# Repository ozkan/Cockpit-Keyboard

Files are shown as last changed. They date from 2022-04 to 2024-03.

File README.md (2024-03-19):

# Cockpit Keyboard

A hot swap system column staggered mechanical keyboard, running QMK Firmware on Pro Micro controllers. 

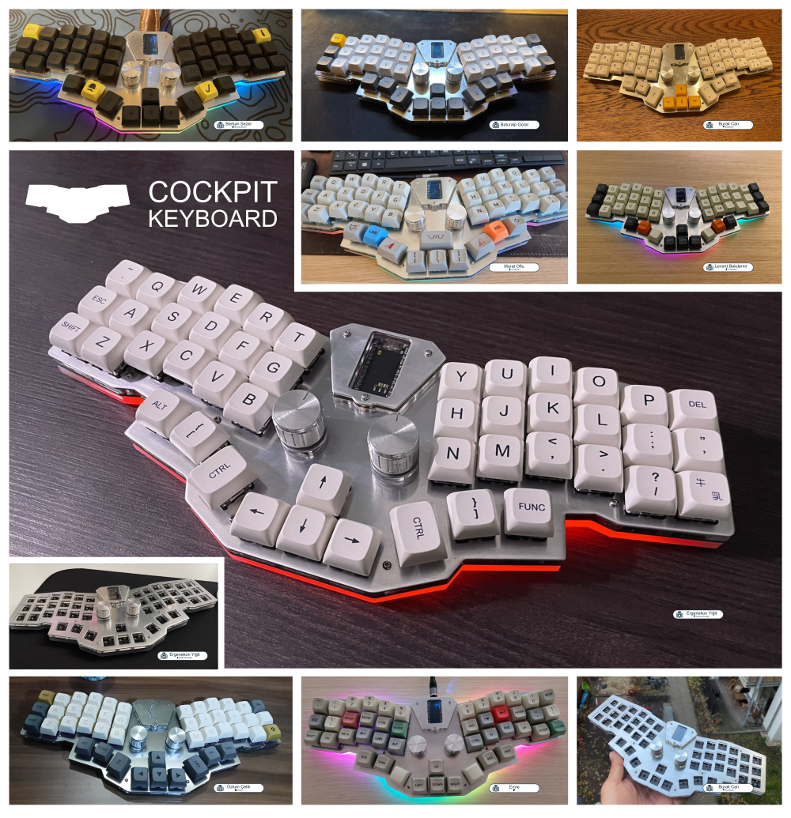
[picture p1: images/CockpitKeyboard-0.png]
Cockpit Keyboard


## Bill of Materials

| Qty  | Descript |
|---|---|
| 1 | PCB board |
| 1 | Arduino Pro Micro |
| 1 | ProMicro socket 24 pin wide or 2.54 mm pitch female header |
| 48 | Diode 1N4148 THT |
| 2 | EC11 Rotary Encoder |
| 2 | Encoder knob |
| 46 | MX Compatible Key Switch (3pin or 5pin) |
| 46 | MX Compatible Keycap (1U) |
| 13 | M2 Spacer 5mm or 6mm (Standoff ) |
| 26 | M2 Screw 5mm |
| 1 | [Top Plate (1.2mm aluminium or acrylic)](acrylic-plate/) |
| 1 | [Upper Middle Plate (4mm acrylic)](acrylic-plate/) |
| 1 | [Lower Middle Plate (3mm acrylic)](acrylic-plate/) |
| 1 | [Bottom Plate (2mm or 3mm acrylic)](acrylic-plate/) |
| 1 | [Pro Micro Cover (2mm or 3mm acrylic)](acrylic-plate/) |
| 1 | 8 channel WS2812 5050 RGB LED |
| 1 | Tact Switch 6X6 4mm |

## Schematic
schematic

## Firmware
Link to qmk-fork: [https://github.com/ozkan/Cockpit-QMK-config](https://github.com/ozkan/Cockpit-QMK-config)    
Link to zmk-fork: [https://github.com/ozkan/Cockpit-ZMK-config](https://github.com/ozkan/Cockpit-ZMK-config)

### Turkey Mechanical Keyboard Community
Telegram: [mechistanbul](https://t.me/mechistanbul) 

## Thanks
Huge shoutout to [Arda Kılıçdağı ](https://github.com/Ardakilic) for tons of advice and help.

<p align="center">

</p> 
<p align="center">
<a href="https://pcbway.com" >PCBWay</a> graciously offered to sponsor the prototype build of this keyboard   <br>
Thanks PCBWay
</p>

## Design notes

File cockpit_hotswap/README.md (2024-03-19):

# Cockpit Keyboard

> [!WARNING]  
> This version (cockpit_hotswap) has not yet been tested. 

### Bill of Materials

| Qty  | Descript |
|---|---|
| 1 | PCB board |
| 1 | Arduino Pro Micro |
| 1 | ProMicro socket 24 pin wide or 2.54 mm pitch female header |
| 46 | Kaihl Hot-swap sockets |
| 48 | 1N4148 SOD123 Diodes |
| 14 | WS2812B RGB LED Chip, 5050 SMD |
| 1 | Tact Switch RS-282G05A3 |
| 1 | 7-Pin On/Off 1P2T SPDT MSK-12C02 SMD Toggle Slide Switch |
| 2 | EC11 Rotary Encoder |
| 2 | Encoder knob |
| 46 | MX Compatible Key Switch (3pin or 5pin) |
| 46 | MX Compatible Keycap (1U) |
| 13 | M2 Spacer 7mm (Standoff) |
| 26 | M2 Screw 5mm |
| 1 | [Top Plate (1.2mm aluminium or acrylic)](acrylic-plate/) |
| 1 | [Upper Middle Plate (4mm acrylic)](acrylic-plate/) |
| 1 | [Lower Middle Plate (3mm acrylic)](acrylic-plate/) |
| 1 | [Bottom Plate (2mm or 3mm acrylic)](acrylic-plate/) |
| 1 | [Pro Micro Cover (2mm or 3mm acrylic)](acrylic-plate/) |

### PCB Renders 

| | |  
|:---:|:---:|
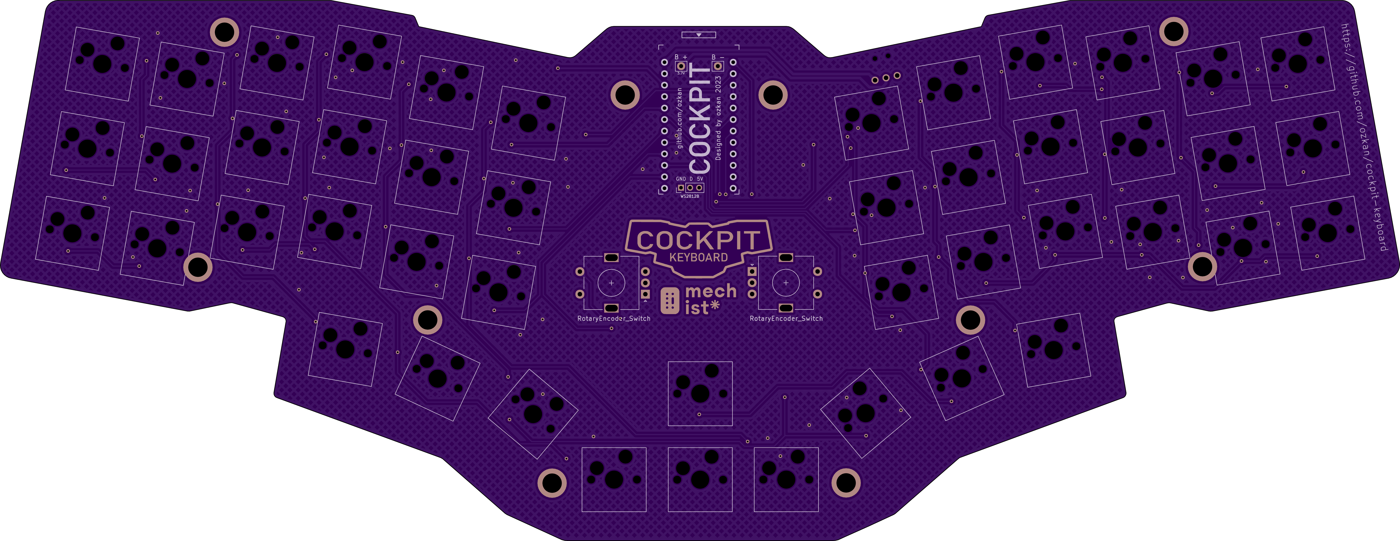
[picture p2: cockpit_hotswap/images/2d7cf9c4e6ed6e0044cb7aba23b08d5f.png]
PCB Top Layer
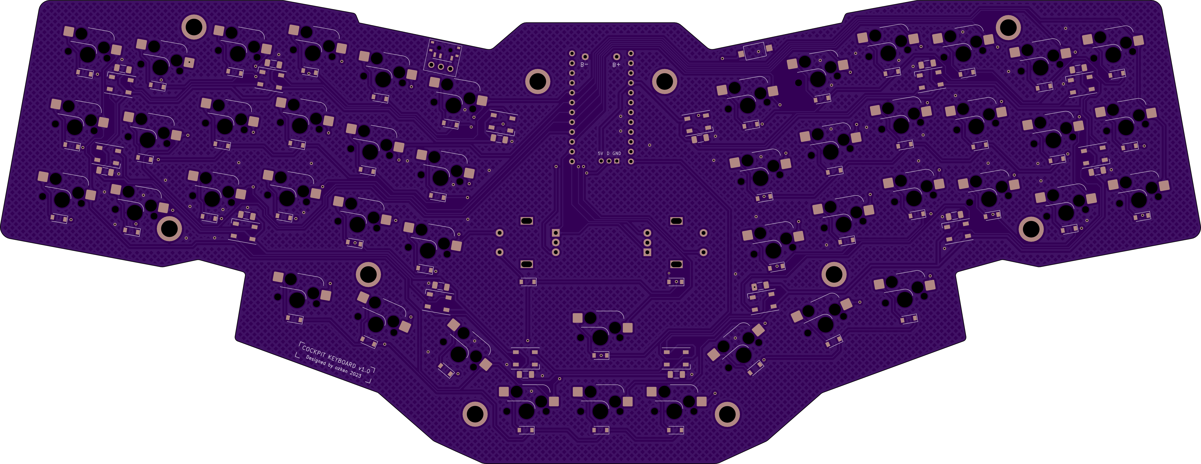
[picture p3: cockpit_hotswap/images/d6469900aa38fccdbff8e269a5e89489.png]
PCB Bottom Layer)
|  | |
|PCB top, full ground plane |PCB bottom, full ground plane|

### Case

| | |  
|:---:|:---:|
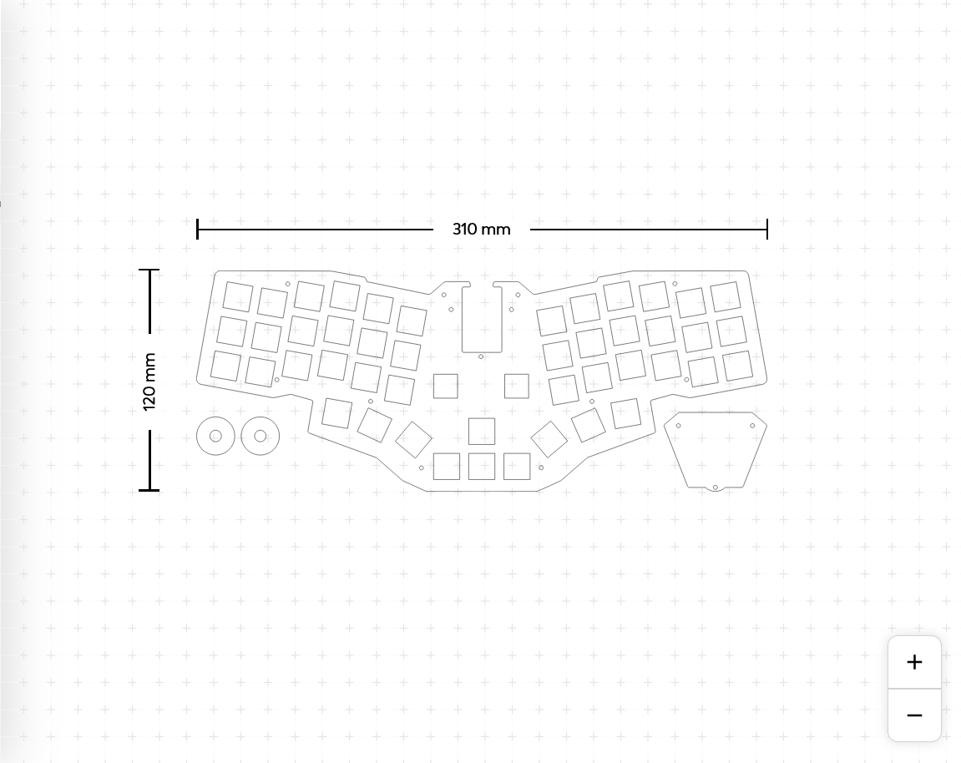
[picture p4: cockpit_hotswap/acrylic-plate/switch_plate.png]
Swtich Plate)
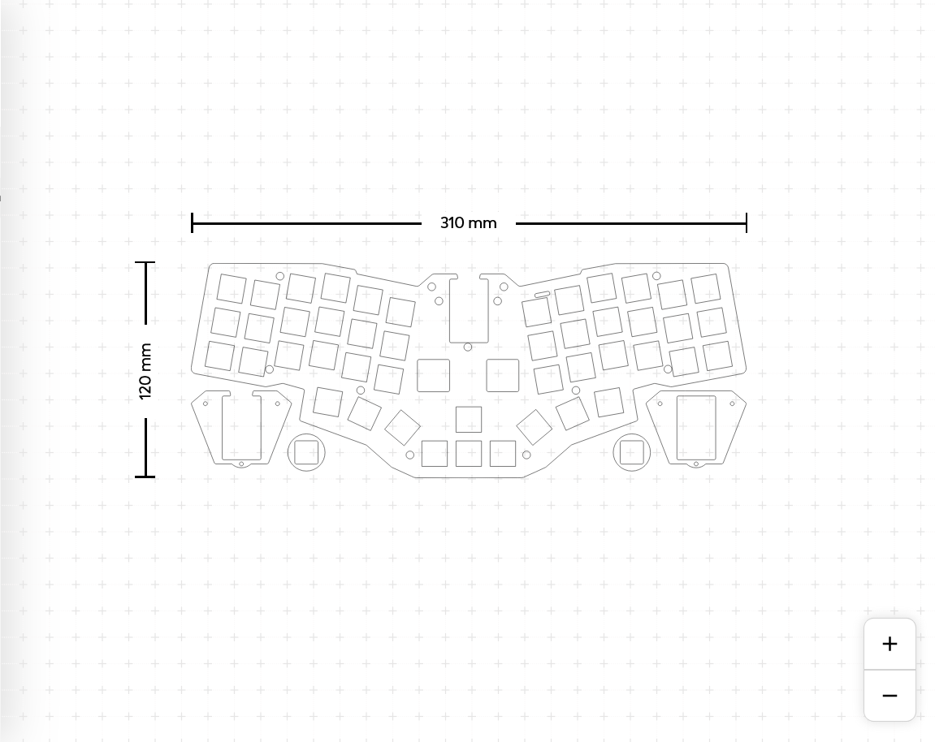
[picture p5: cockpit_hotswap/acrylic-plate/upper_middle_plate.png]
Upper Middle Plate)
|  |  |
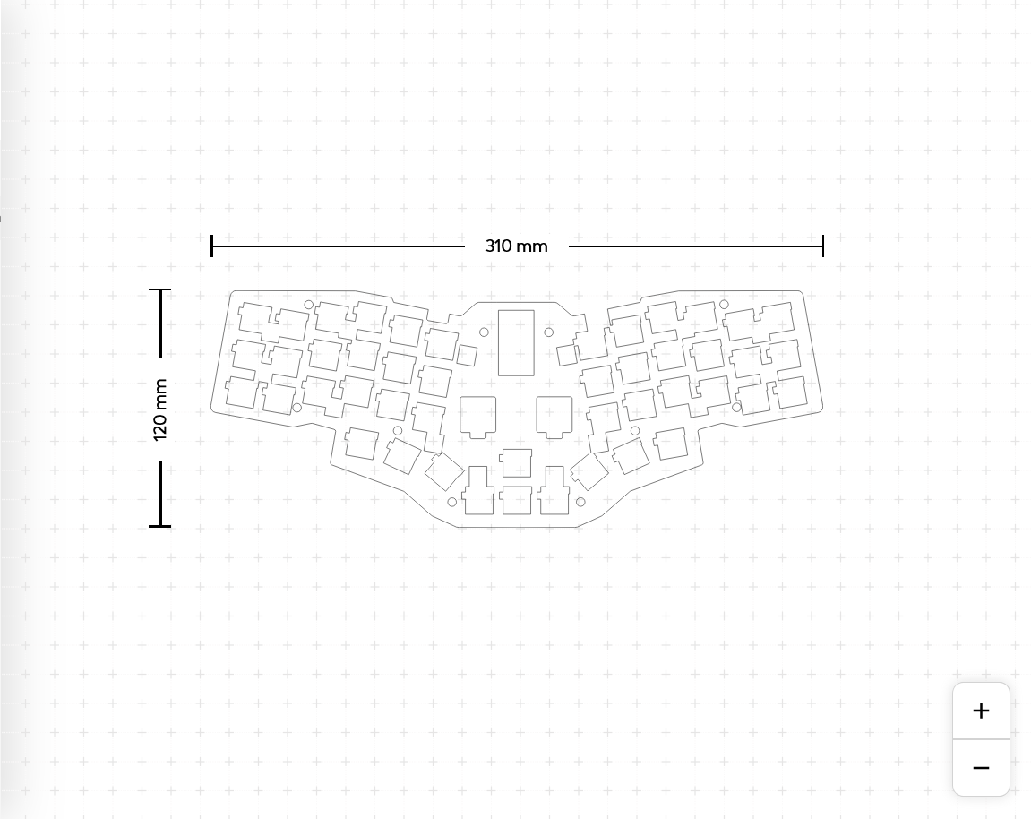
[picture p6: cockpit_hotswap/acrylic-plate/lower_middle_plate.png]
Lower Middle Plate)
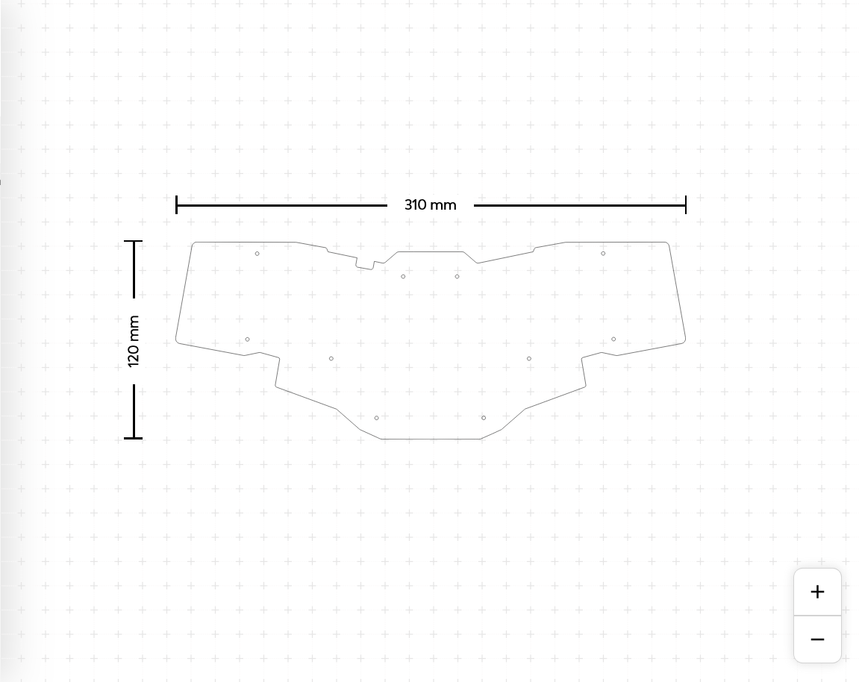
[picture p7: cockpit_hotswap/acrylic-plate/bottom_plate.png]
Bottom Plate)
| | |

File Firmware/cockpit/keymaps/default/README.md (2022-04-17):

### COLEMAK

```
╭──────┬──────┬──────┬──────┬──────┬──────╮                   ╭──────┬──────┬──────┬──────┬──────┬──────╮
│  TAB │  Q   │  W   │  F   │  P   │  G   │                   │  J   │  L   │  U   │  Y   │   ;  │ BSPC │
├──────┼──────┼──────┼──────┼──────┼──────┤                   ├──────┼──────┼──────┼──────┼──────┼──────┤
│ CTRL │  A   │  R   │  S   │NAV T │  D   │                   │  H   │  N   │  E   │  I   │  O   │   "  │
├──────┼──────┼──────┼──────┼──────┼──────┤                   ├──────┼──────┼──────┼──────┼──────┼──────┤
│SFT_CL│ALT Z │CTL X │SFT C │  V   │  B   │                   │  K   │  M   │SFT , │CTL . │ALT / │ ENT  │
╰──────┴──────┴──────┴──────┴──────┴──────┼─────────┬─────────┼──────┴──────┴──────┴──────┴──────┴──────╯
                                          │  MPLY   │  MUTE   │
                    ╭──────┬──────┬───────┼─────────┴─────────┼──────┬──────┬──────╮
                    │  ALT │LOWER │  FNL  │                   │ FNR  │RAISE │  WIN │
                    ╰──────┴──────┴───────┴─────┬──────┬──────┴──────┴──────┴──────╯
                                                │  UP  │
                                         ╭──────┼──────┼──────╮
                                         │ LEFT │ DOWN │ RIGHT│
                                         ╰──────┴──────┴──────╯
```

### LOWER
    
```
╭──────┬──────┬──────┬──────┬──────┬──────╮                   ╭──────┬──────┬──────┬──────┬──────┬──────╮
│ ESC  │      │      │      │      │      │                   │  (   │  )   │  =   │  &   │  |   │ DEL  │
├──────┼──────┼──────┼──────┼──────┼──────┤                   ├──────┼──────┼──────┼──────┼──────┼──────┤
│      │      │      │      │      │      │                   │  {   │  }   │  _   │  $   │  #   │   '  │
├──────┼──────┼──────┼──────┼──────┼──────┤                   ├──────┼──────┼──────┼──────┼──────┼──────┤
│      │      │      │      │      │      │                   │  [   │  ]   │  <   │  >   │  \   │ ENT  │
╰──────┴──────┴──────┴──────┴──────┴──────┼─────────┬─────────┼──────┴──────┴──────┴──────┴──────┴──────╯
                                          │  MPLY   │  MUTE   │
                    ╭──────┬──────┬───────┼─────────┴─────────┼──────┬──────┬──────╮
                    │  ALT │LOWER │  FNL  │                   │ FNR  │RAISE │  WIN │
                    ╰──────┴──────┴───────┴─────┬──────┬──────┴──────┴──────┴──────╯
                                                │  UP  │
                                         ╭──────┼──────┼──────╮
                                         │ LEFT │ DOWN │ RIGHT│
                                         ╰──────┴──────┴──────╯
```

### RAISE

```
╭──────┬──────┬──────┬──────┬──────┬──────╮                   ╭──────┬──────┬──────┬──────┬──────┬──────╮
│ ESC  │  /   │  1   │  2   │  3   │  -   │                   │  F1  │  F2  │  F3  │  F4  │      │      │
├──────┼──────┼──────┼──────┼──────┼──────┤                   ├──────┼──────┼──────┼──────┼──────┼──────┤
│      │  *   │  4   │  5   │  6   │  +   │                   │  F5  │  F6  │  F7  │  F8  │      │      │
├──────┼──────┼──────┼──────┼──────┼──────┤                   ├──────┼──────┼──────┼──────┼──────┼──────┤
│      │  %   │  7   │  8   │  9   │  0   │                   │  F9  │  F10 │ F11  │  F1  │      │      │
╰──────┴──────┴──────┴──────┴──────┴──────┼─────────┬─────────┼──────┴──────┴──────┴──────┴──────┴──────╯
                                          │  MPLY   │  MUTE   │
                    ╭──────┬──────┬───────┼─────────┴─────────┼──────┬──────┬──────╮
                    │  ALT │LOWER │  FNL  │                   │ FNR  │RAISE │  WIN │
                    ╰──────┴──────┴───────┴─────┬──────┬──────┴──────┴──────┴──────╯
                                                │  UP  │
                                         ╭──────┼──────┼──────╮
                                         │ LEFT │ DOWN │ RIGHT│
                                         ╰──────┴──────┴──────╯
```                                        

### FNR

```
╭──────┬──────┬──────┬──────┬──────┬──────╮                   ╭──────┬──────┬──────┬──────┬──────┬──────╮
│ ESC  │      │      │  €   │  £   │  Ğ   │                   │      │      │      │      │      │      │
├──────┼──────┼──────┼──────┼──────┼──────┤                   ├──────┼──────┼──────┼──────┼──────┼──────┤
│      │  !   │  @   │  Ş   │  ₺   │      │                   │      │      │      │      │      │      │
├──────┼──────┼──────┼──────┼──────┼──────┤                   ├──────┼──────┼──────┼──────┼──────┼──────┤
│      │      │      │  Ç   │      │      │                   │      │      │      │      │      │      │
╰──────┴──────┴──────┴──────┴──────┴──────┼─────────┬─────────┼──────┴──────┴──────┴──────┴──────┴──────╯
                                          │  MPLY   │  MUTE   │
                    ╭──────┬──────┬───────┼─────────┴─────────┼──────┬──────┬──────╮
                    │  ALT │LOWER │  FNL  │                   │ FNR  │RAISE │  WIN │
                    ╰──────┴──────┴───────┴─────┬──────┬──────┴──────┴──────┴──────╯
                                                │  UP  │
                                         ╭──────┼──────┼──────╮
                                         │ LEFT │ DOWN │ RIGHT│
                                         ╰──────┴──────┴──────╯
```

### FNL

```
╭──────┬──────┬──────┬──────┬──────┬──────╮                   ╭──────┬──────┬──────┬──────┬──────┬──────╮
│ ESC  │      │      │      │      │      │                   │      │      │  Ü   │      │  :   │ DEL  │
├──────┼──────┼──────┼──────┼──────┼──────┤                   ├──────┼──────┼──────┼──────┼──────┼──────┤
│      │      │      │      │      │      │                   │      │      │  I   │  I   │  Ö   │   '  │
├──────┼──────┼──────┼──────┼──────┼──────┤                   ├──────┼──────┼──────┼──────┼──────┼──────┤
│      │      │      │      │      │      │                   │      │      │  ^   │  ~   │  ?   │ ENT  │
╰──────┴──────┴──────┴──────┴──────┴──────┼─────────┬─────────┼──────┴──────┴──────┴──────┴──────┴──────╯
                                          │  MPLY   │  MUTE   │
                    ╭──────┬──────┬───────┼─────────┴─────────┼──────┬──────┬──────╮
                    │  ALT │LOWER │  FNL  │                   │ FNR  │RAISE │  WIN │
                    ╰──────┴──────┴───────┴─────┬──────┬──────┴──────┴──────┴──────╯
                                                │  UP  │
                                         ╭──────┼──────┼──────╮
                                         │ LEFT │ DOWN │ RIGHT│
                                         ╰──────┴──────┴──────╯                                    
```

### ARROW

```
╭──────┬──────┬──────┬──────┬──────┬──────╮                   ╭──────┬──────┬──────┬──────┬──────┬──────╮
│ ESC  │      │      │      │      │      │                   │C_PREV│ PGUP │  UP  │      │      │      │
├──────┼──────┼──────┼──────┼──────┼──────┤                   ├──────┼──────┼──────┼──────┼──────┼──────┤
│      │      │      │      │NAV T │      │                   │ HOME │ LEFT │ DOWN │ RGHT │ END  │MPLY  │
├──────┼──────┼──────┼──────┼──────┼──────┤                   ├──────┼──────┼──────┼──────┼──────┼──────┤
│      │      │      │      │      │      │                   │C_NEXT│PGDOWN│      │VLDOWN│ VLUP │MUTE  │
╰──────┴──────┴──────┴──────┴──────┴──────┼─────────┬─────────┼──────┴──────┴──────┴──────┴──────┴──────╯
                                          │  MPLY   │  MUTE   │
                    ╭──────┬──────┬───────┼─────────┴─────────┼──────┬──────┬──────╮
                    │  ALT │LOWER │  FNL  │                   │ FNR  │RAISE │  WIN │
                    ╰──────┴──────┴───────┴─────┬──────┬──────┴──────┴──────┴──────╯
                                                │  UP  │
                                         ╭──────┼──────┼──────╮
                                         │ LEFT │ DOWN │ RIGHT│
                                         ╰──────┴──────┴──────╯

``` 
### ADJUST

```
╭──────┬──────┬──────┬──────┬──────┬──────╮                   ╭──────┬──────┬──────┬──────┬──────┬──────╮
│      │      │      │      │      │      │                   │      │      │      │      │ QWERY│COLEMK│
├──────┼──────┼──────┼──────┼──────┼──────┤                   ├──────┼──────┼──────┼──────┼──────┼──────┤
│      │      │      │      │      │      │                   │      │      │      │      │      │      │
├──────┼──────┼──────┼──────┼──────┼──────┤                   ├──────┼──────┼──────┼──────┼──────┼──────┤
│      │      │      │      │      │      │                   │ RESET│      │      │      │      │      │
╰──────┴──────┴──────┴──────┴──────┴──────┼─────────┬─────────┼──────┴──────┴──────┴──────┴──────┴──────╯
                                          │  MPLY   │  MUTE   │
                    ╭──────┬──────┬───────┼─────────┴─────────┼──────┬──────┬──────╮
                    │  ALT │LOWER │  FNL  │                   │ FNR  │RAISE │  WIN │
                    ╰──────┴──────┴───────┴─────┬──────┬──────┴──────┴──────┴──────╯
                                                │  UP  │
                                         ╭──────┼──────┼──────╮
                                         │ LEFT │ DOWN │ RIGHT│
                                         ╰──────┴──────┴──────╯
```

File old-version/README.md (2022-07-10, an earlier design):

# Cockpit Keyboard

A hot swap system for Handwire builds column staggered mechanical keyboard, running QMK Firmware on Pro Micro controllers. 

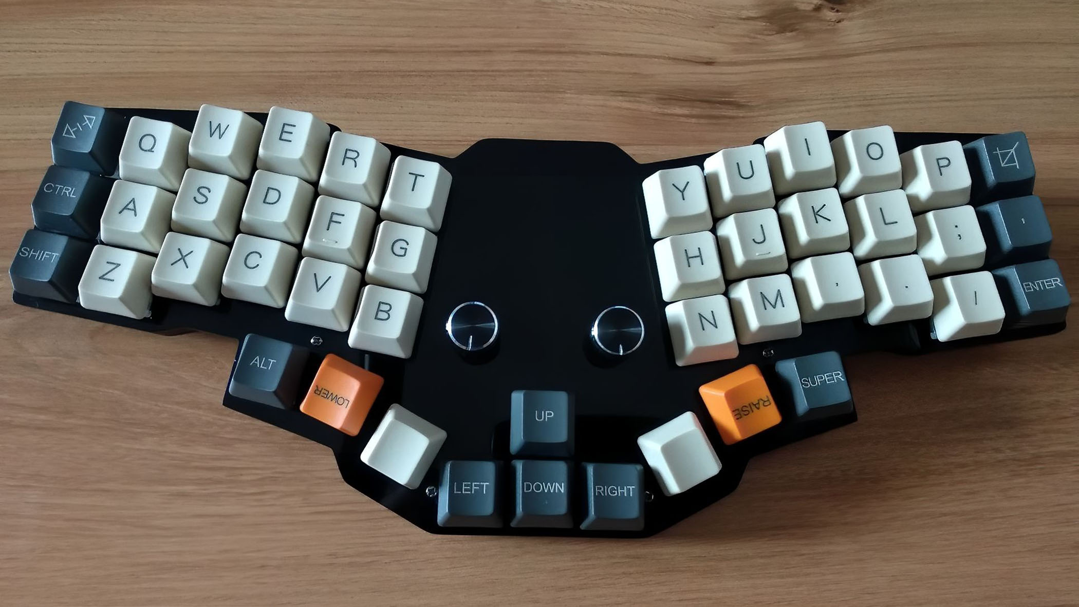
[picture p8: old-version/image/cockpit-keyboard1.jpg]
Cockpit Keyboard
                  
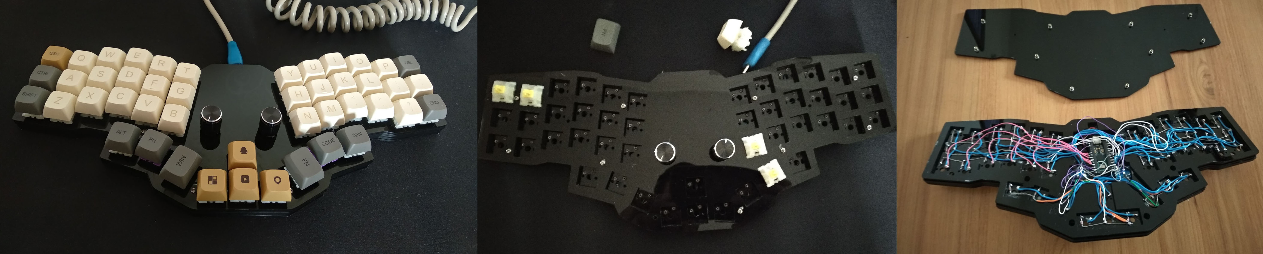
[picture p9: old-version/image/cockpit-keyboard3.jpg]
Cockpit Keyboard
          
## Parts list 

| | Description | Qty  |
| :--- | :----: | ---: |
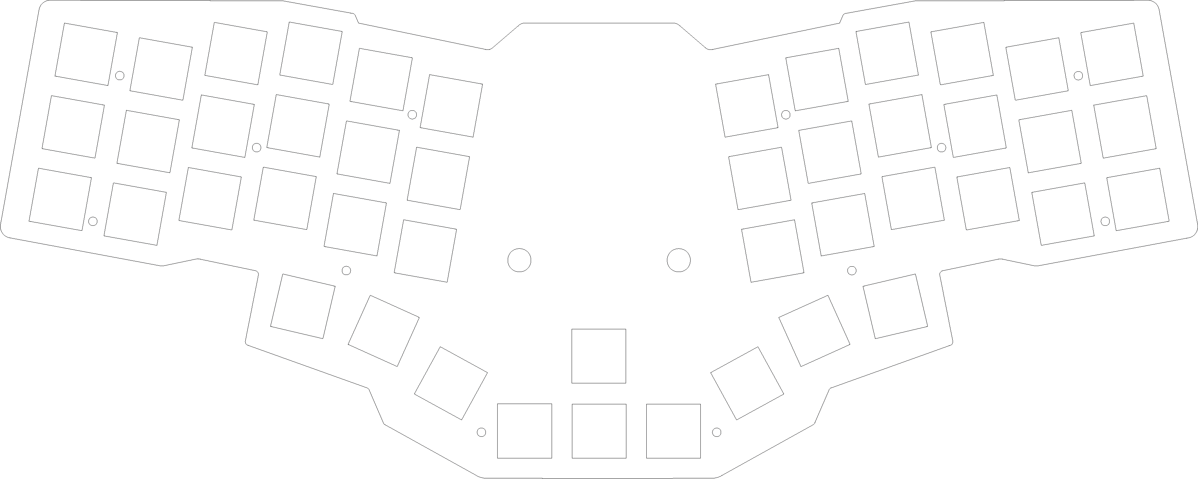
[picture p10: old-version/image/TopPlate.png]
top plate
|  |[Top Plate (1.5mm aluminium or acrylic)](acrylic-plate/top-plate/) | 1 |
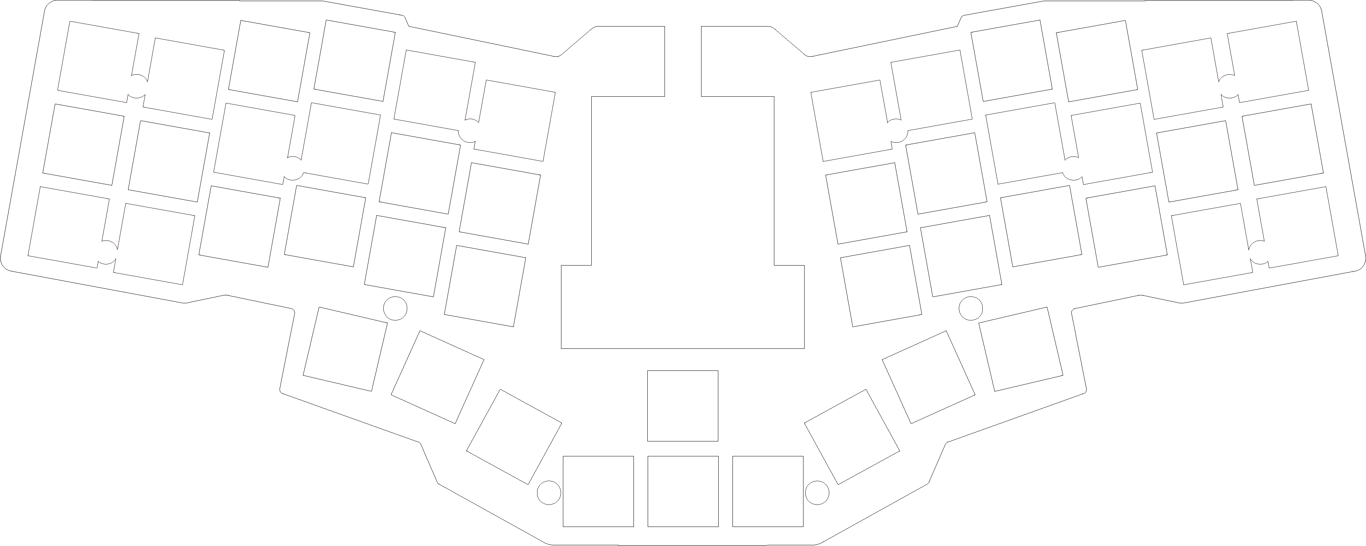
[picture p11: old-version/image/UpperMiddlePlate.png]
upper middle plate
|  |[Upper Middle Plate (3mm acrylic)](acrylic-plate/upper-middle-plate/)| 1 |
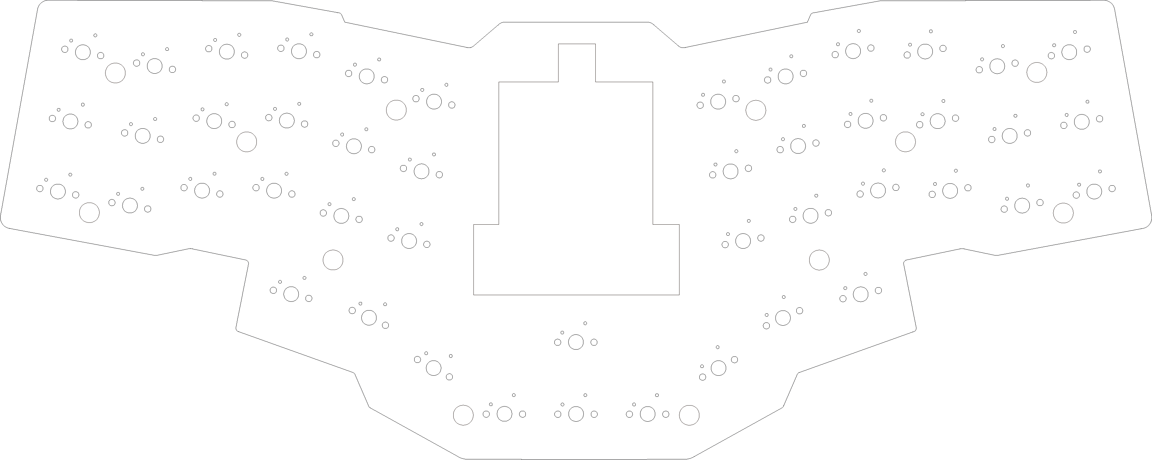
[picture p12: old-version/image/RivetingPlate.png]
riveting plate
|  |[Riveting Plate (2mm acrylic)](acrylic-plate/riveting-plate/) | 1 |
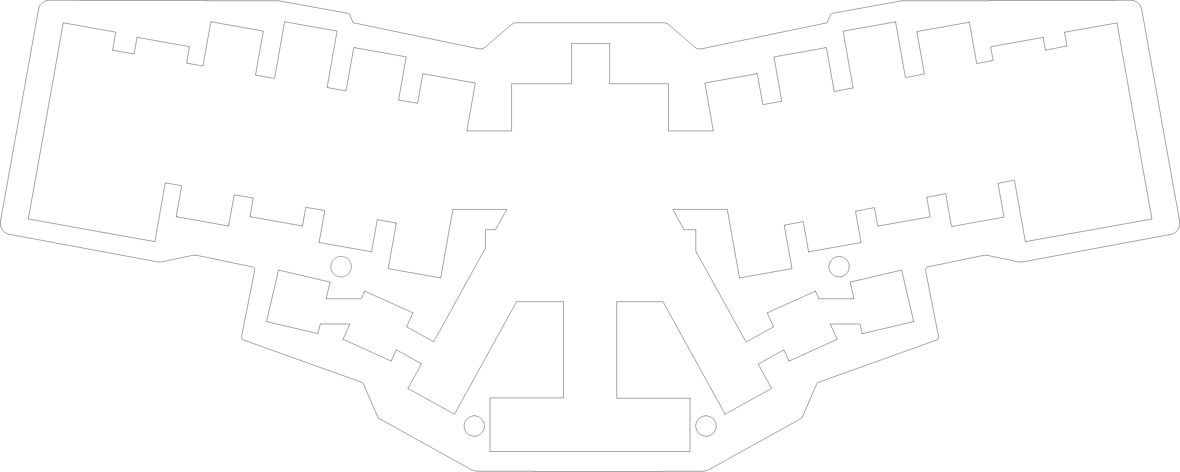
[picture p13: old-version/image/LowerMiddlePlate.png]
lower middle plate
|  |[Lower Middle Plate (3mm acrylic)](acrylic-plate/lower-middle-plate/)| 1 |
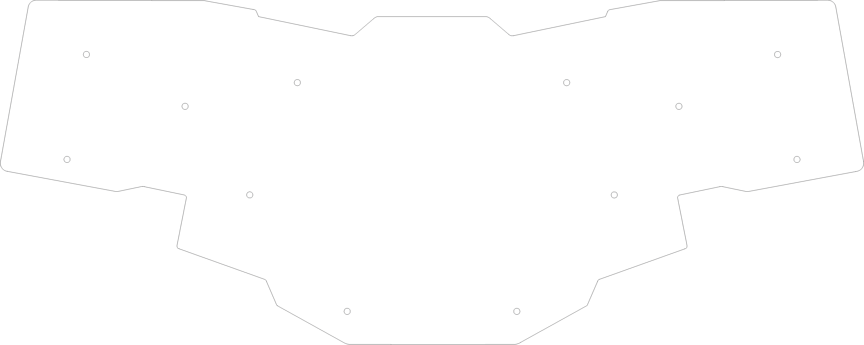
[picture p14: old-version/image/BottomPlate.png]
bottom plate
|  |[Bottom Plate (2mm or 3mm acrylic)](acrylic-plate/bottom-plate/) | 1 |
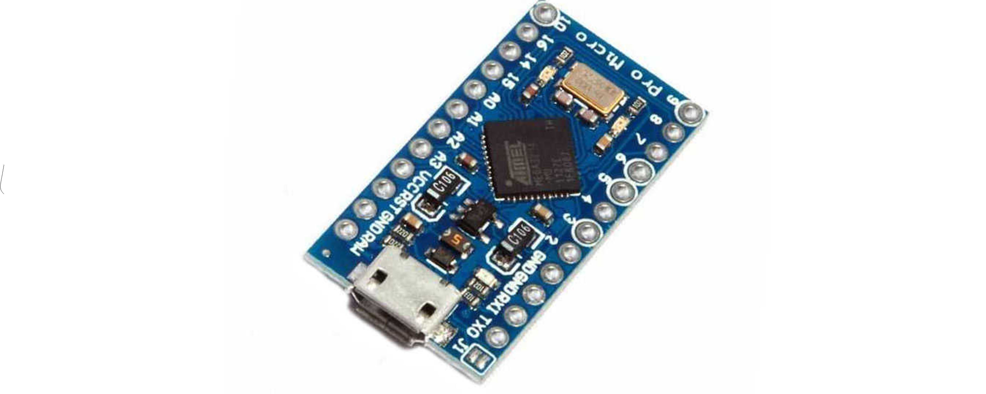
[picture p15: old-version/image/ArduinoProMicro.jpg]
arduino pro micro
|  |Arduino Pro Micro | 1 |
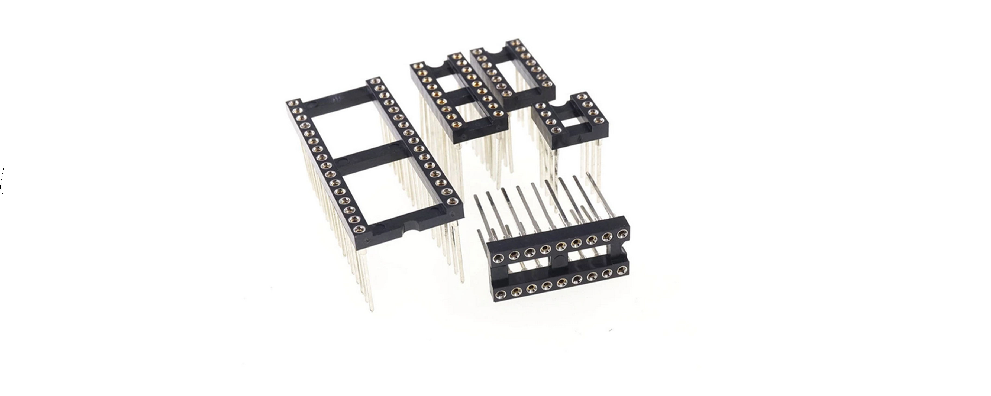
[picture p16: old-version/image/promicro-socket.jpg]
promicro socket
|  |ProMicro Socket 24 Pin Wide (optional) | 1 |
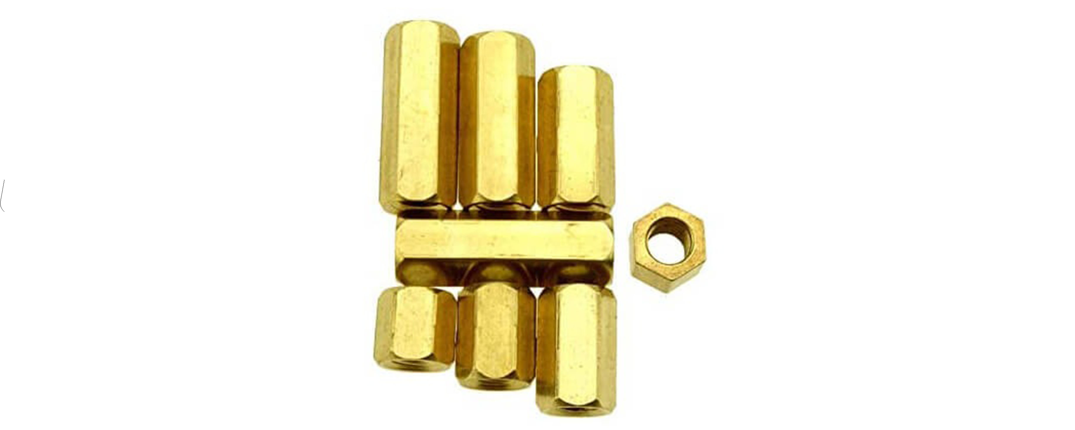
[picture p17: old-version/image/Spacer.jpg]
Spacer
|  |M2 Spacer 5mm or 6mm | 12 |
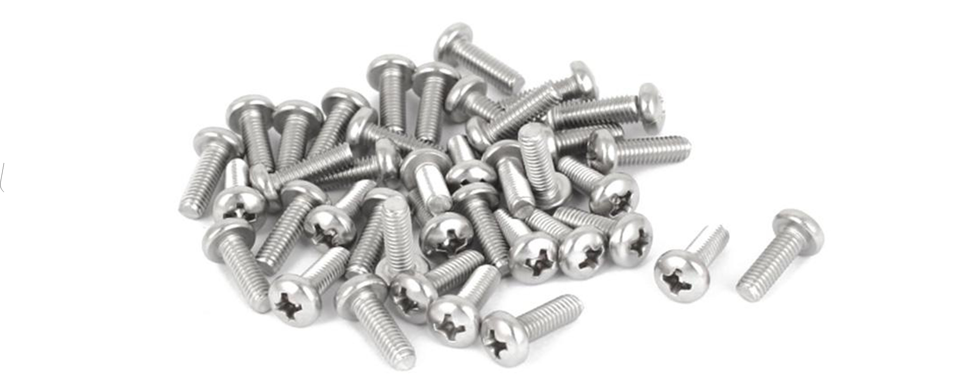
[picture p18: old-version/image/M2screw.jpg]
M2screw
|  |M2 Screw 4mm | 24 |
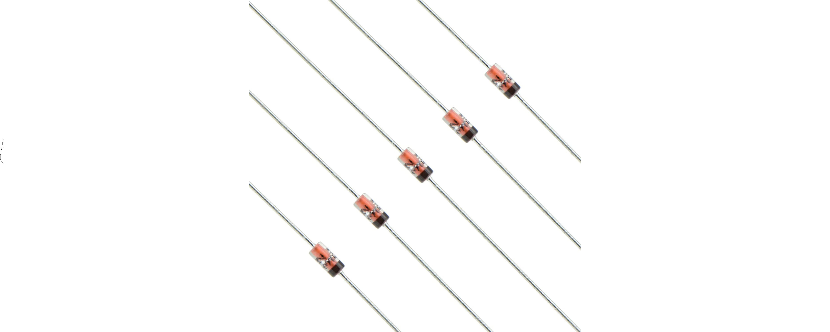
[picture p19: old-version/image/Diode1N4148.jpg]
Diode 1N4148
|  |Diode 1N4148 THT | 48 |
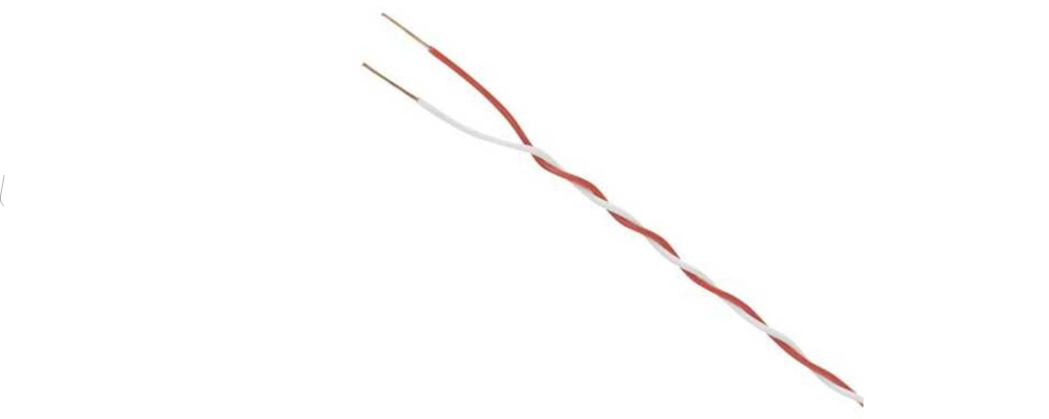
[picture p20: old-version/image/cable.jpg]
cable
|  |Single Core 0.5mm Cable | ~3m  |
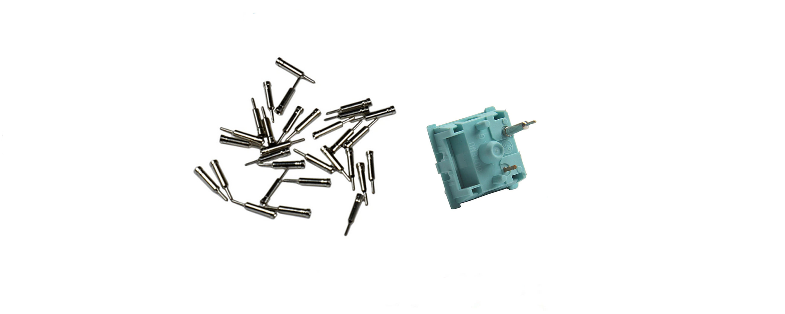
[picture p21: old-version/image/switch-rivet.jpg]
Rivet
|  |Rivet (Hot Swap Sip Socket Similar to Millmax) or 7305-0-15-15-47-27-10-0 Millmax | 92 |
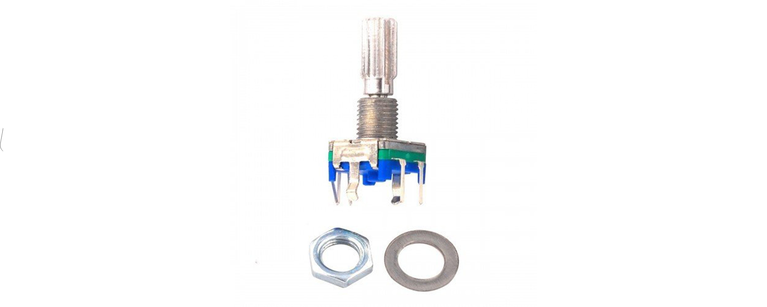
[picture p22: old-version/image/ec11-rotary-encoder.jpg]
Ec11
|  |EC11 Rotary Encoder | 2 |
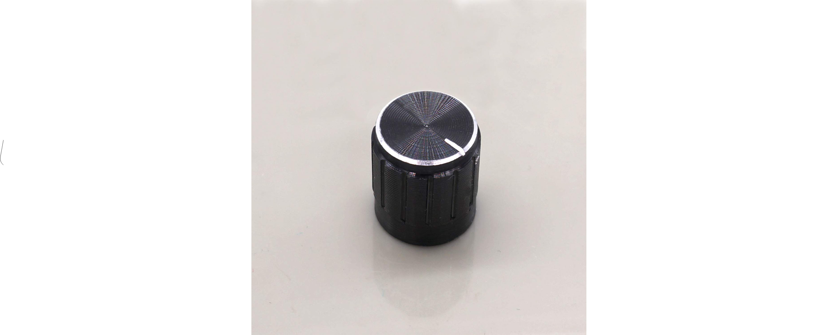
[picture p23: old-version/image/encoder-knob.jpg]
Knob
|  |Knob | 2 |
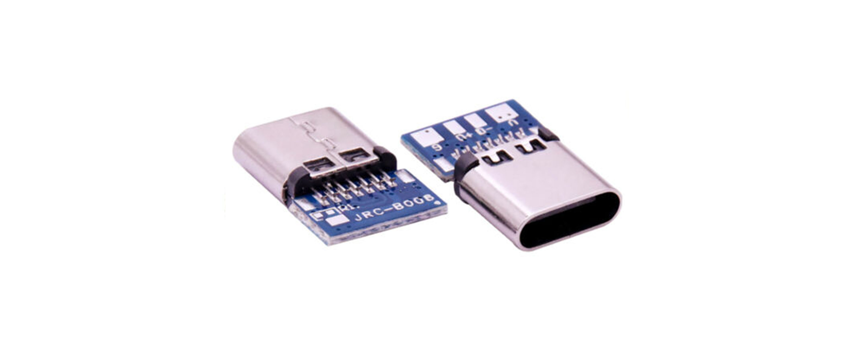
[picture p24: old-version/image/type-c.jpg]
type c
|  |Type C Connector 14 Pin Female | 1 |
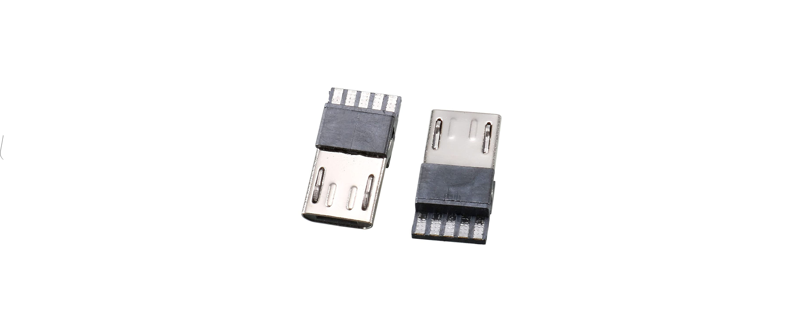
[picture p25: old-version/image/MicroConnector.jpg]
micro connetor
|  |Micro USB Male Type B 5 Terminal Jack Port Solder Connector | 1 |
| switch |MX Compatible Key Switch (3pin or 5pin) | 46 |
| keycaps |MX Compatible Keycap (1U) | 46 |

## Schematic
schematic

## Firmware
[Frimware](Firmware)

### Turkey Mechanical Keyboard Community
[Telegram: mechistanbul](https://t.me/mechistanbul) 

---
Keyboard Maintainer: [ozkan](https://github.com/ozkan)

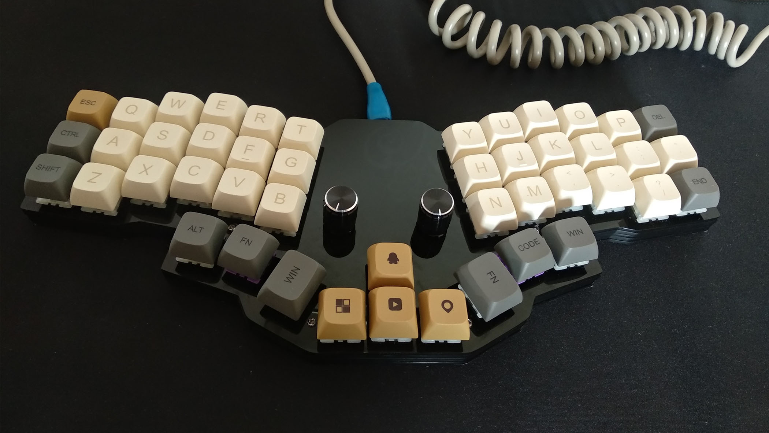
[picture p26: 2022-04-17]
image/cockpit-keyboard2.jpg

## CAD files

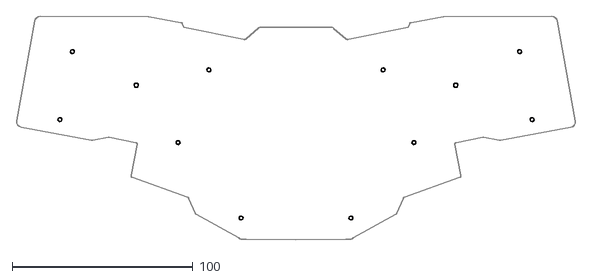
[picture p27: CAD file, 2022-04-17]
acrylic-plate/bottom-plate/BottomPlate.dxf
310.0 x 123.6

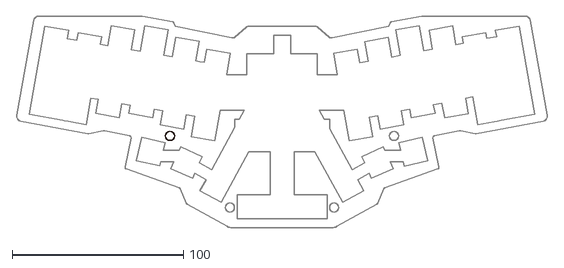
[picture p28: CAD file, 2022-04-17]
acrylic-plate/lower-middle-plate/LowerMiddlePlate.dxf
310.0 x 123.6

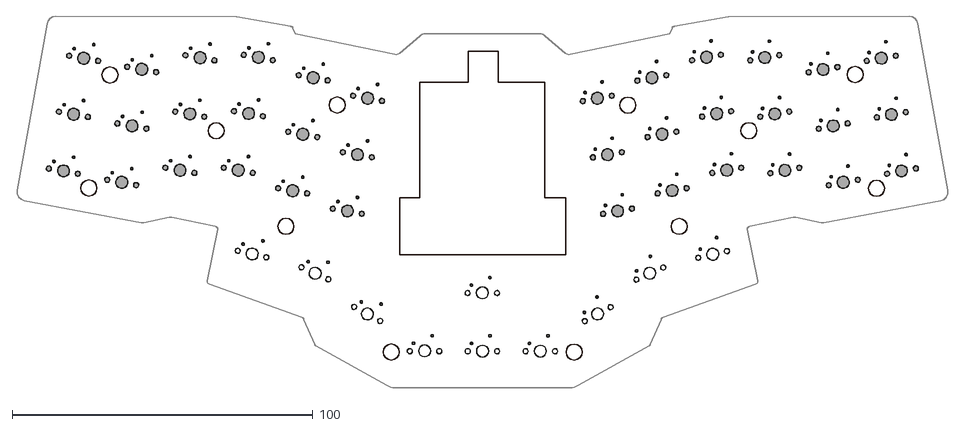
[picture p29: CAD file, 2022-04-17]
acrylic-plate/riveting-plate/RivetingPlate.dxf
310.0 x 123.6

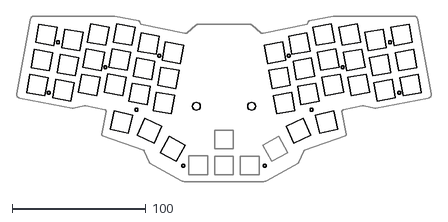
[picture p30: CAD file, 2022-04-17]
acrylic-plate/top-plate/TopPlate.dxf
310.0 x 123.6

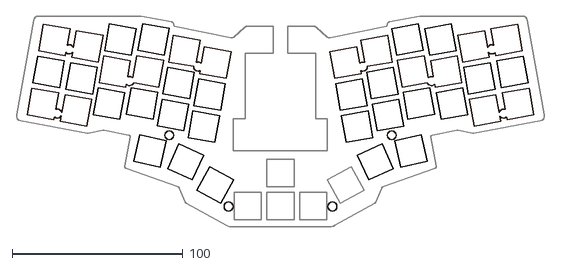
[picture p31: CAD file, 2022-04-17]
acrylic-plate/upper-middle-plate/UpperMiddlePlate.dxf
310.0 x 123.6

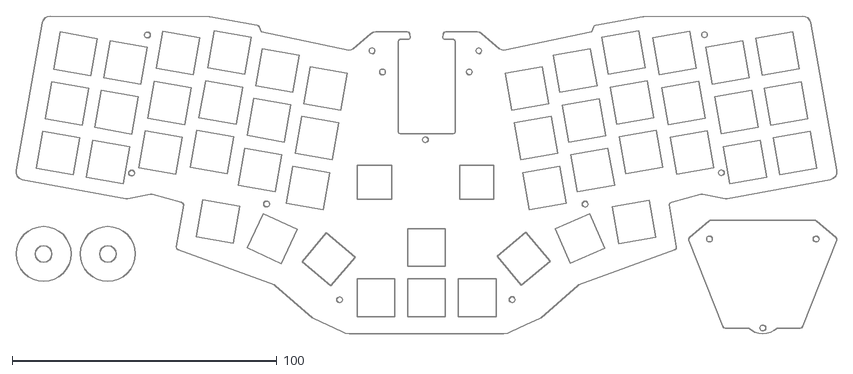
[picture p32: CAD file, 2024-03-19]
cockpit_hotswap/acrylic-plate/switch_plate.dxf
310.0 x 120.0

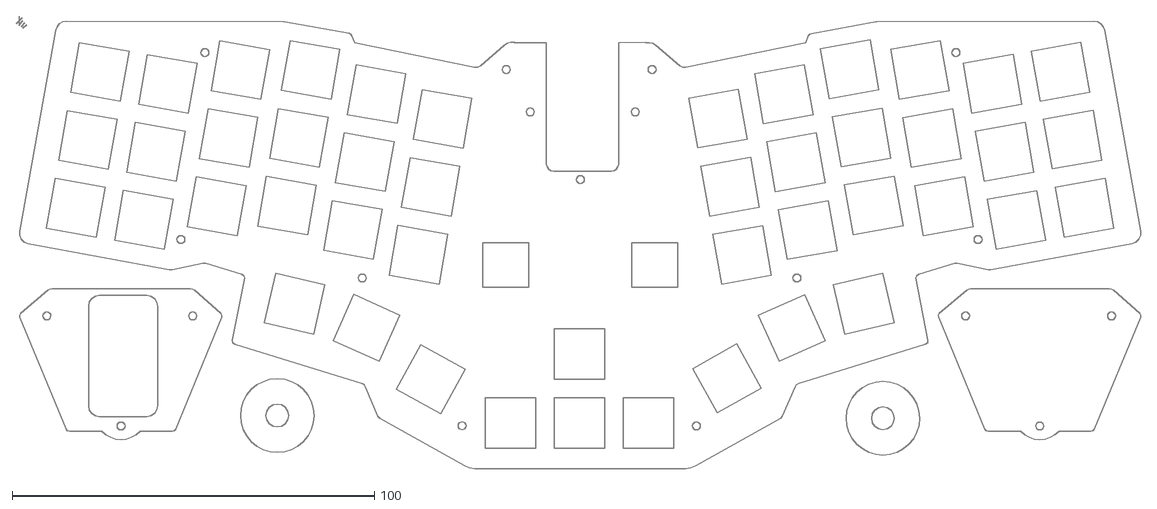
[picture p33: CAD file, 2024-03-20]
cockpit_soldered/acrylic-plate/top.dxf
310.3 x 125.0

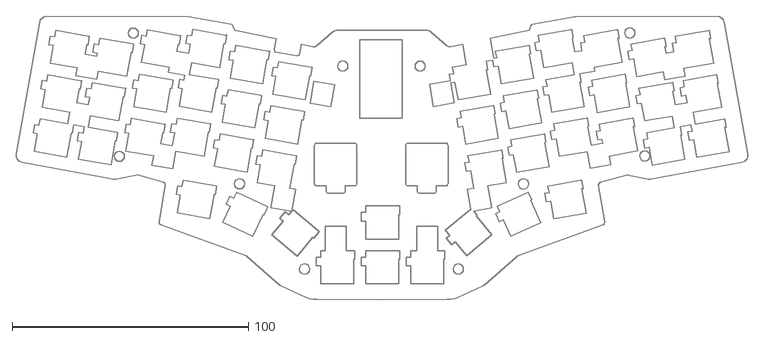
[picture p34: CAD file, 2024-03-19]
cockpit_hotswap/acrylic-plate/lower_middle_plate.dxf
310.0 x 120.0

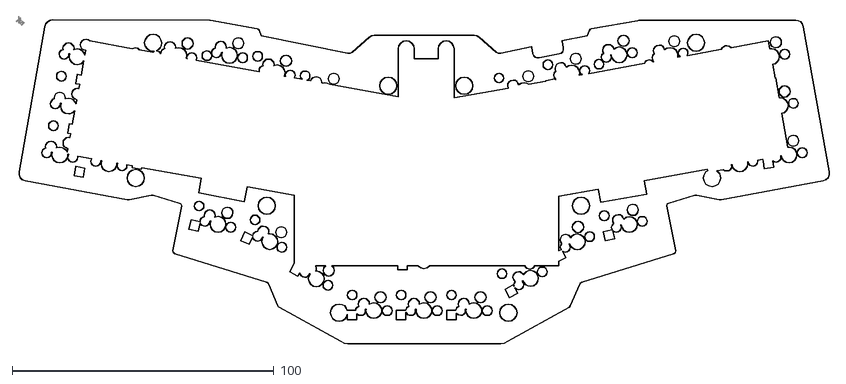
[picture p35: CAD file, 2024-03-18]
cockpit_soldered/acrylic-plate/lower-middle-plate.dxf
310.4 x 125.1

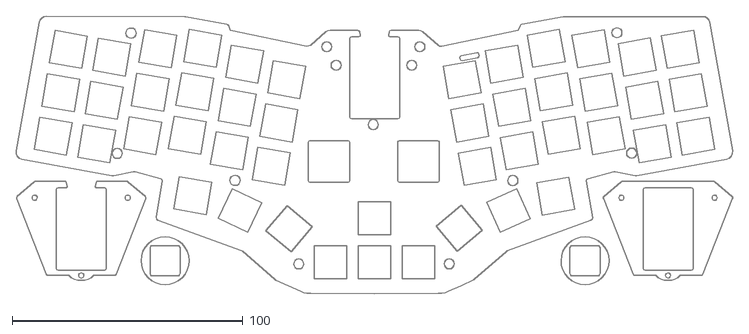
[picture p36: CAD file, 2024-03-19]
cockpit_hotswap/acrylic-plate/upper_middle_plate.dxf
310.1 x 119.9

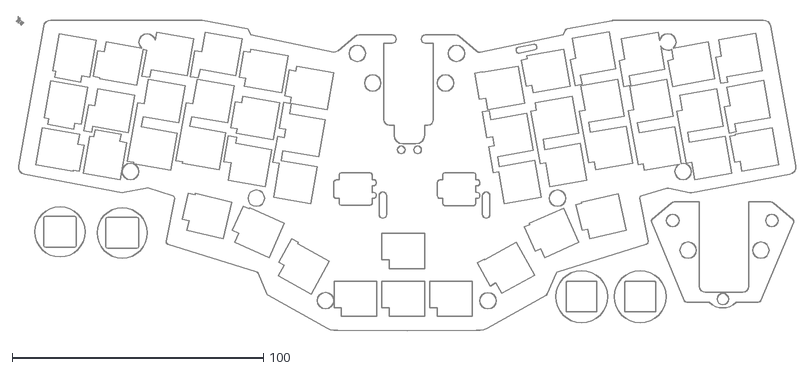
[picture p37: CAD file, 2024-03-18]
cockpit_soldered/acrylic-plate/upper-middle-plate.dxf
310.3 x 125.1

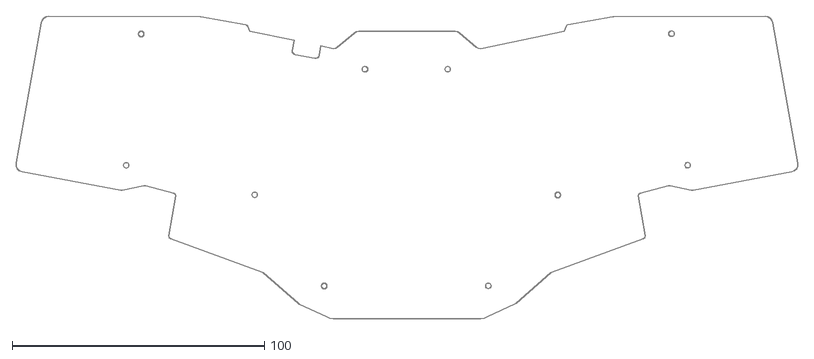
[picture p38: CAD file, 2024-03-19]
cockpit_hotswap/acrylic-plate/bottom_plate.dxf
310.2 x 120.1

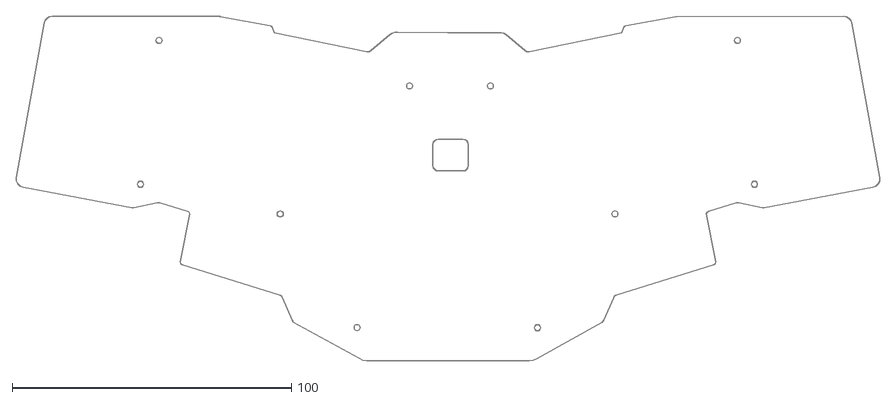
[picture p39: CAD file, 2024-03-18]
cockpit_soldered/acrylic-plate/bottom.dxf
309.4 x 123.6

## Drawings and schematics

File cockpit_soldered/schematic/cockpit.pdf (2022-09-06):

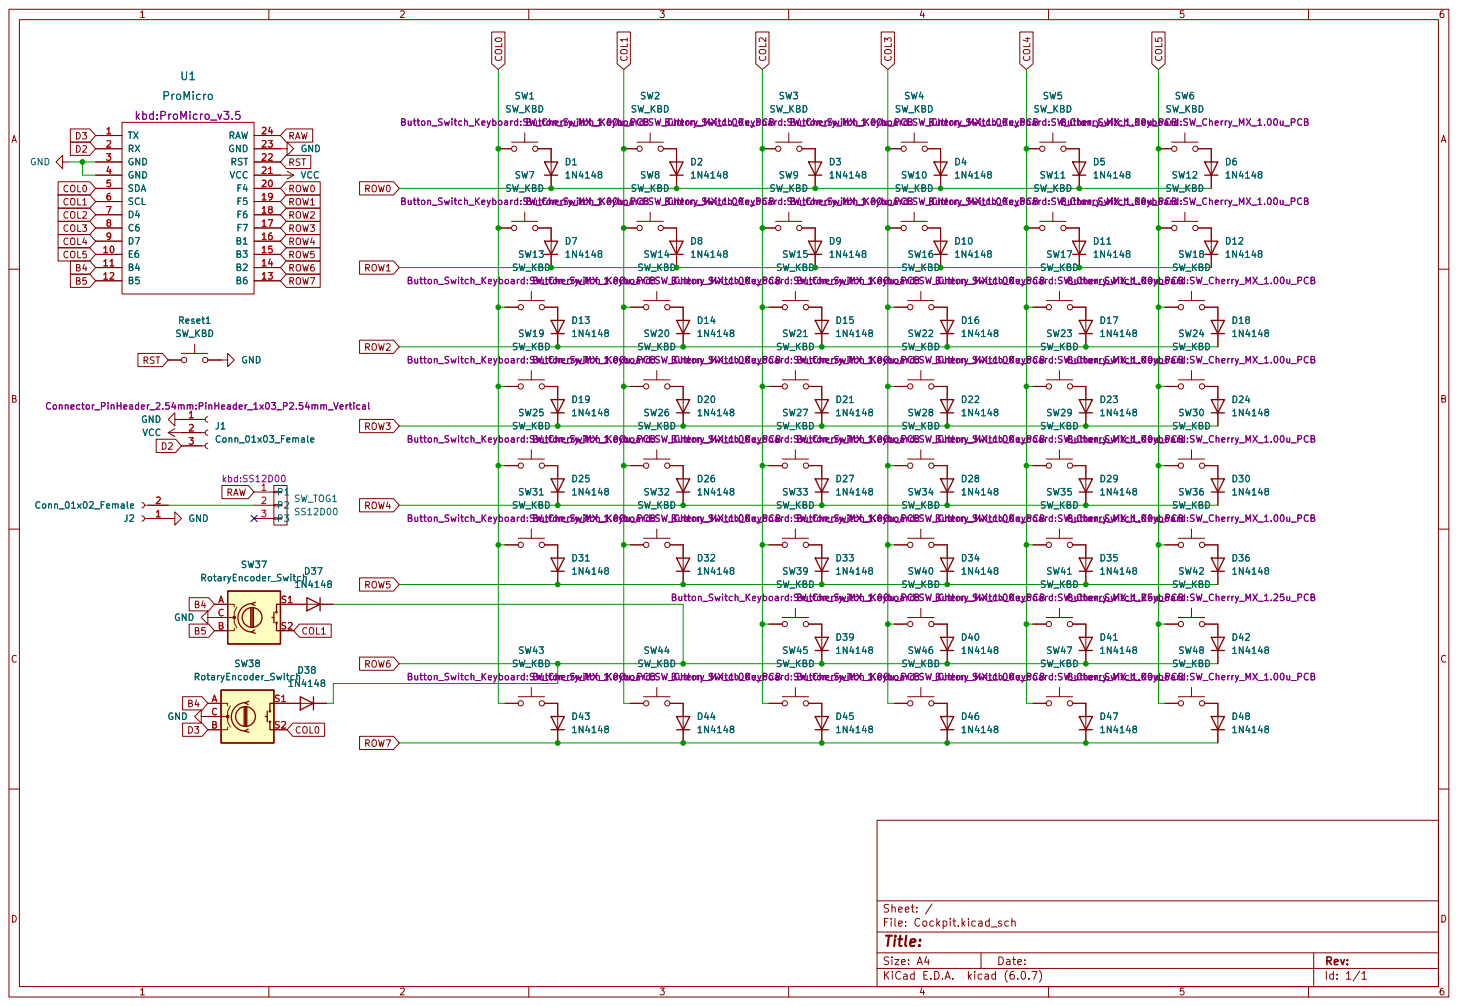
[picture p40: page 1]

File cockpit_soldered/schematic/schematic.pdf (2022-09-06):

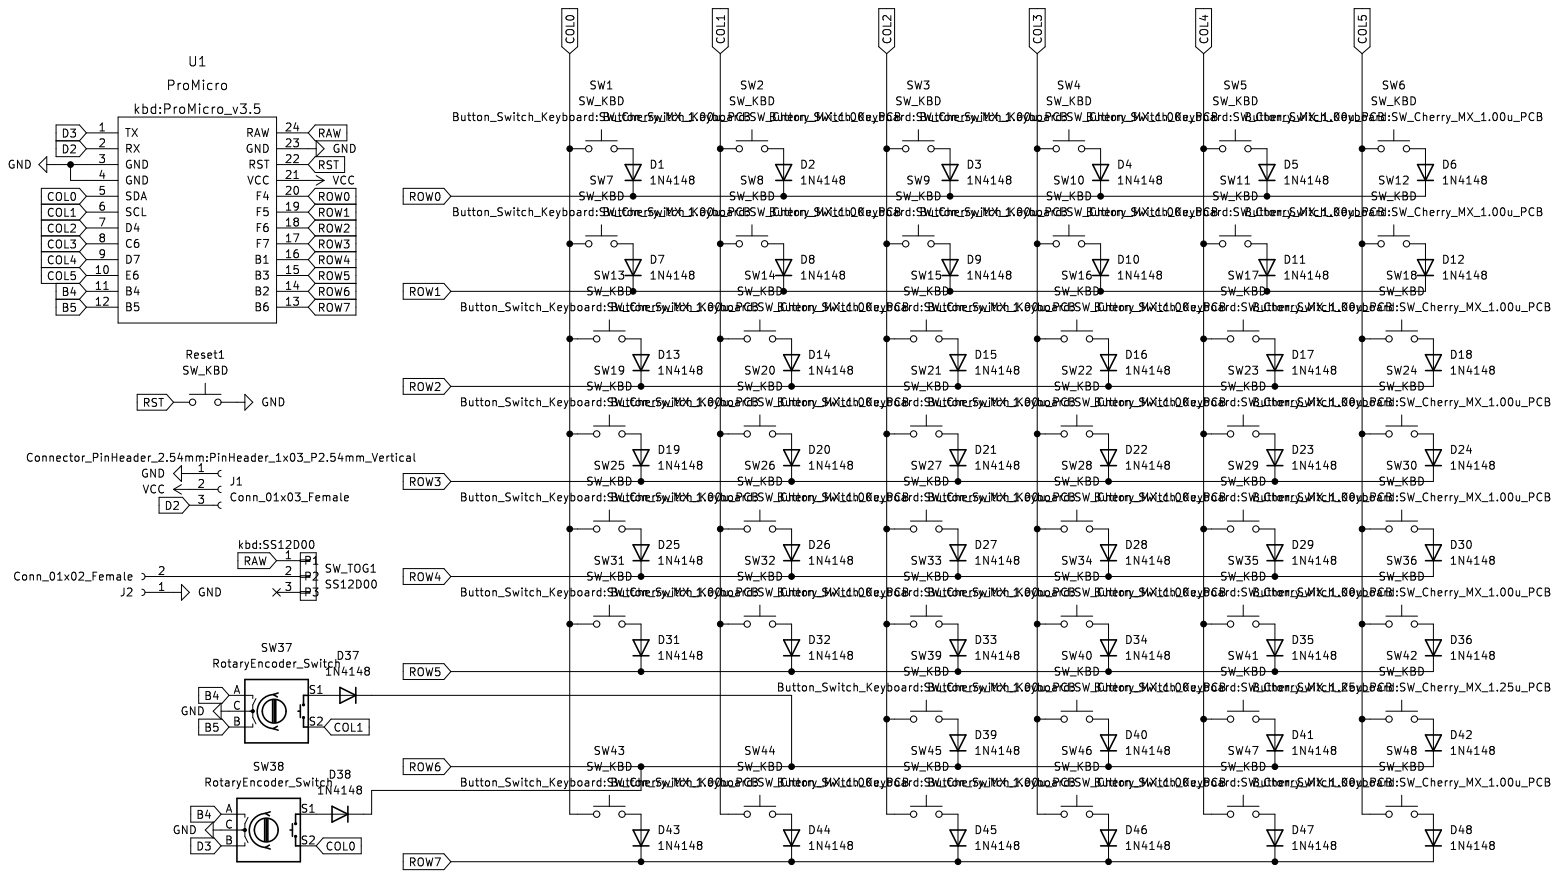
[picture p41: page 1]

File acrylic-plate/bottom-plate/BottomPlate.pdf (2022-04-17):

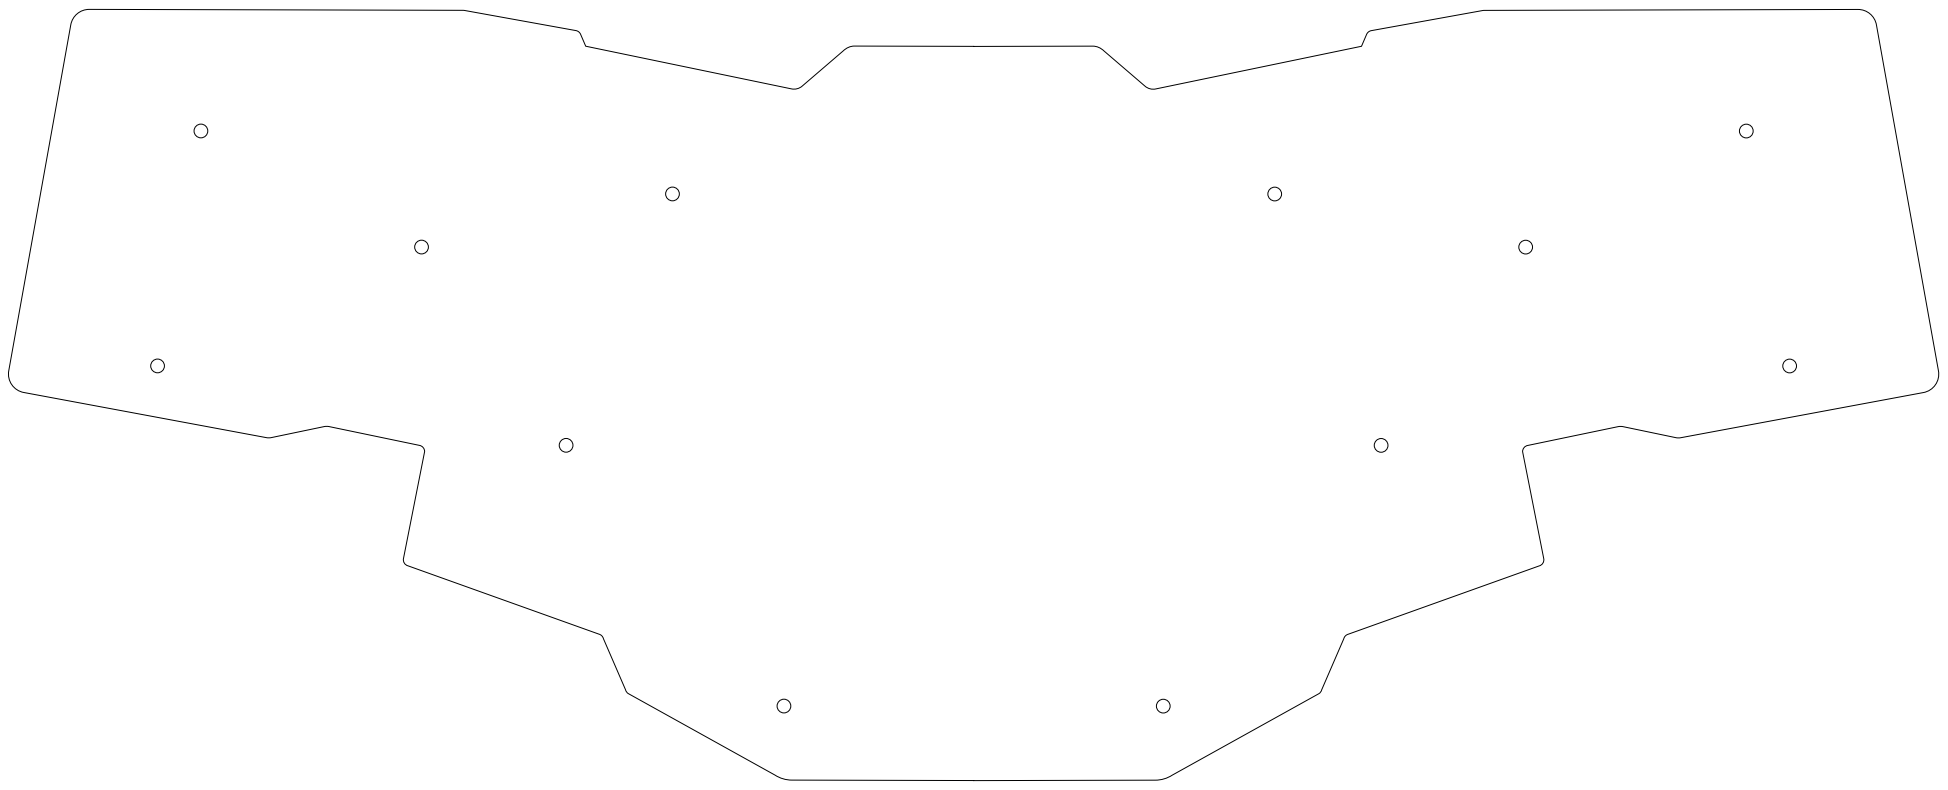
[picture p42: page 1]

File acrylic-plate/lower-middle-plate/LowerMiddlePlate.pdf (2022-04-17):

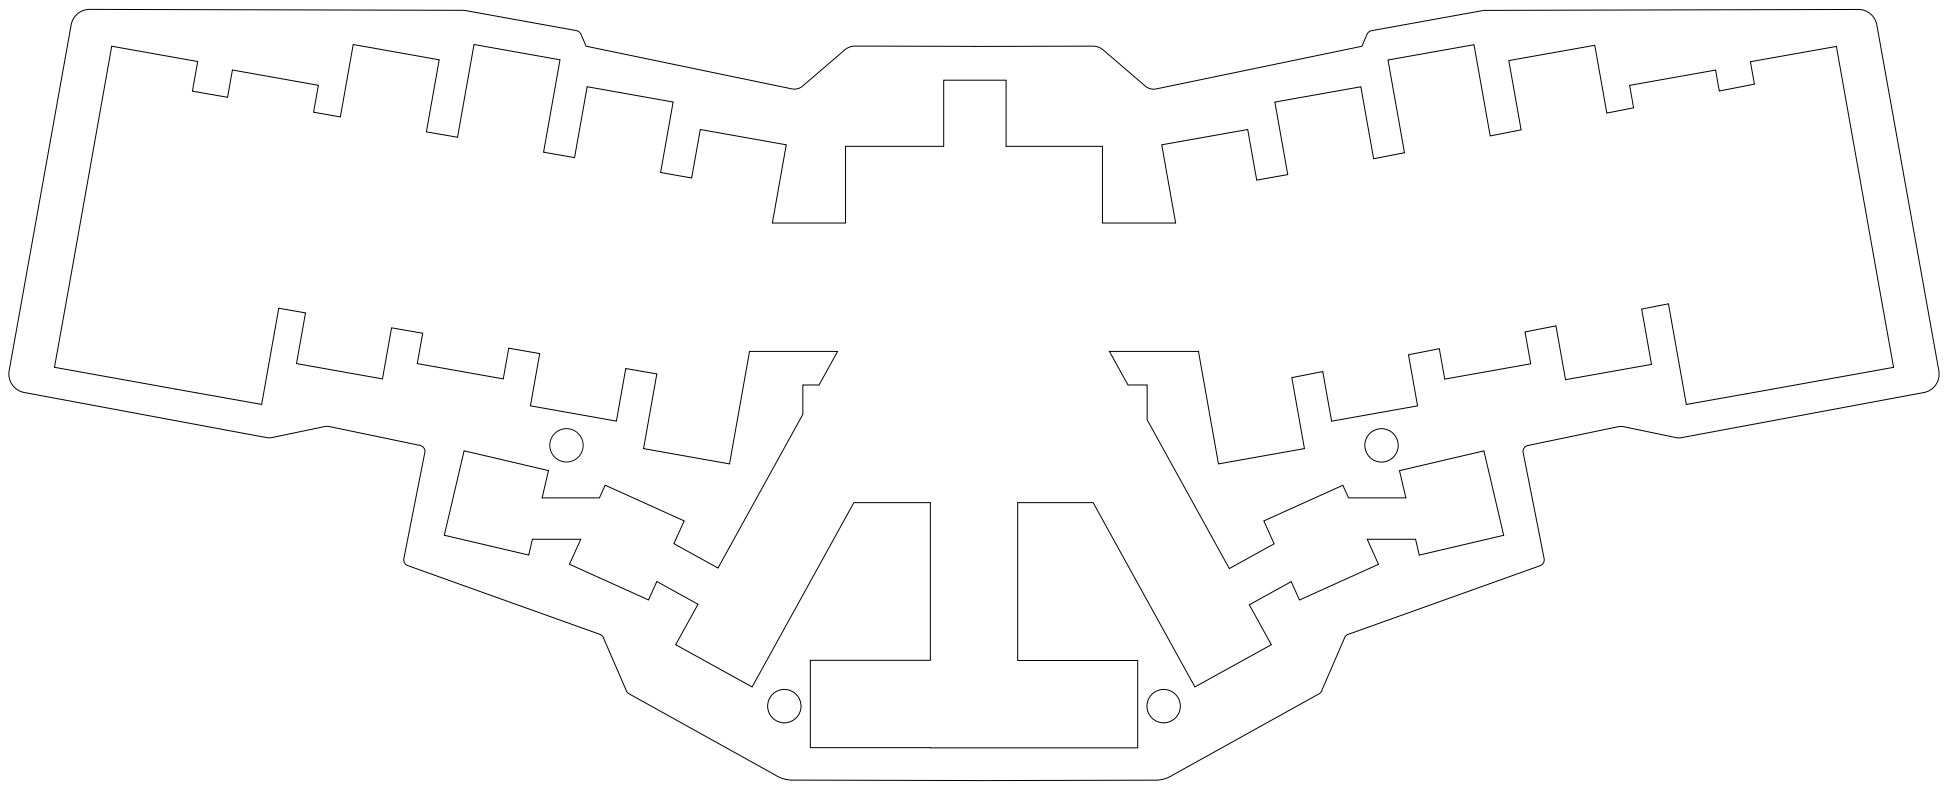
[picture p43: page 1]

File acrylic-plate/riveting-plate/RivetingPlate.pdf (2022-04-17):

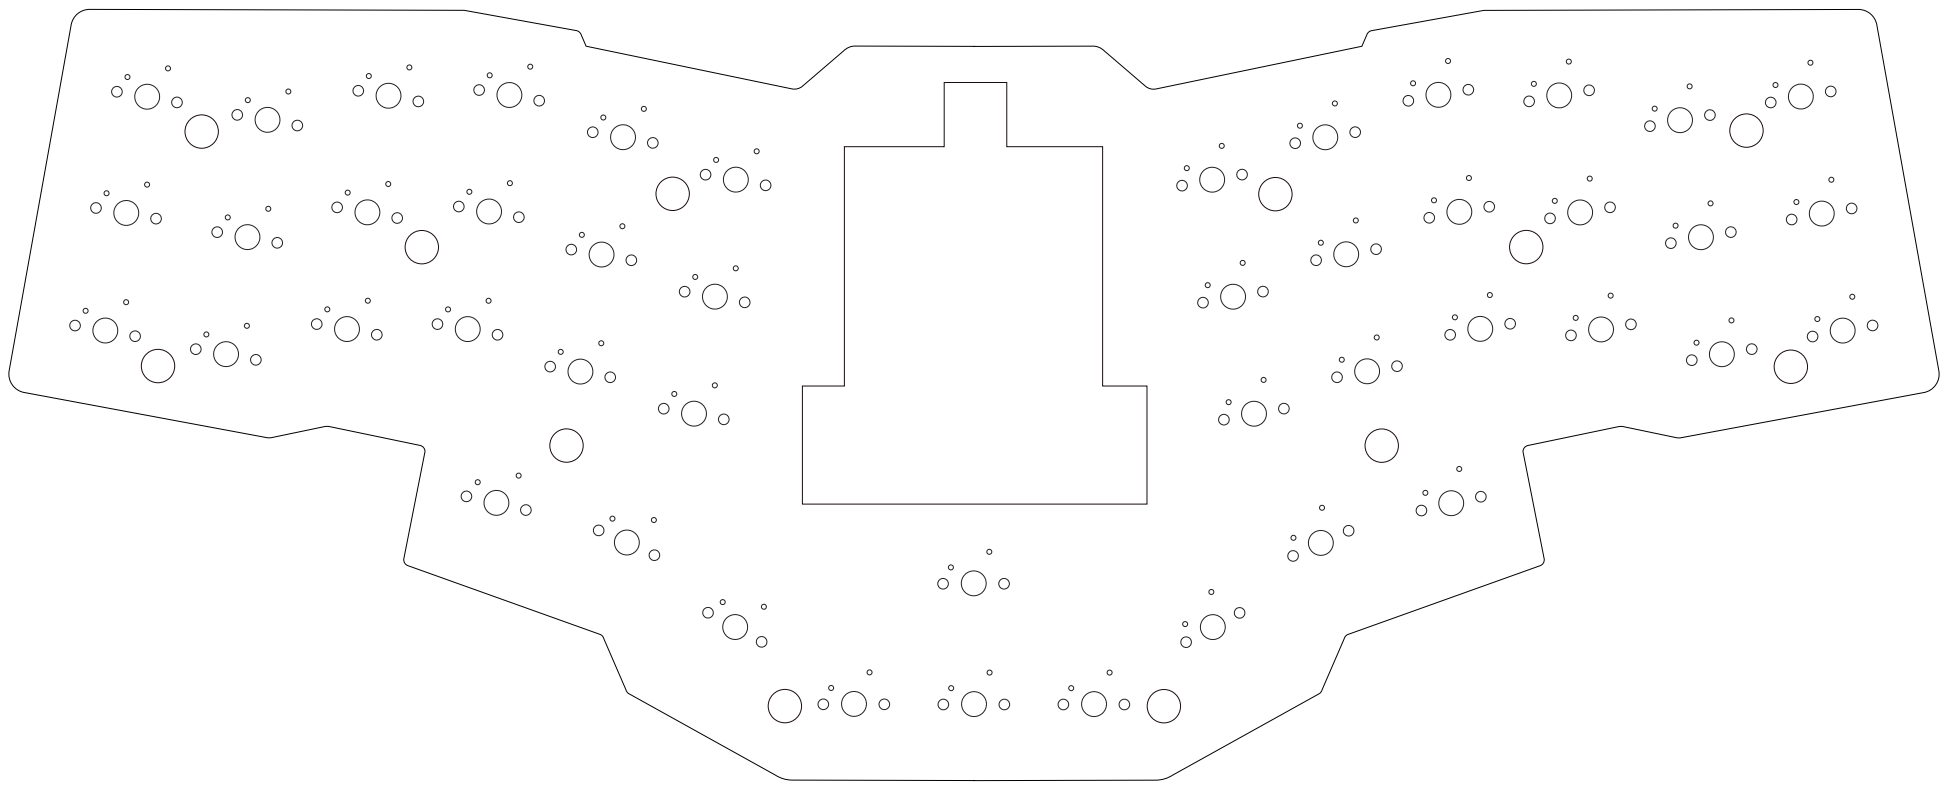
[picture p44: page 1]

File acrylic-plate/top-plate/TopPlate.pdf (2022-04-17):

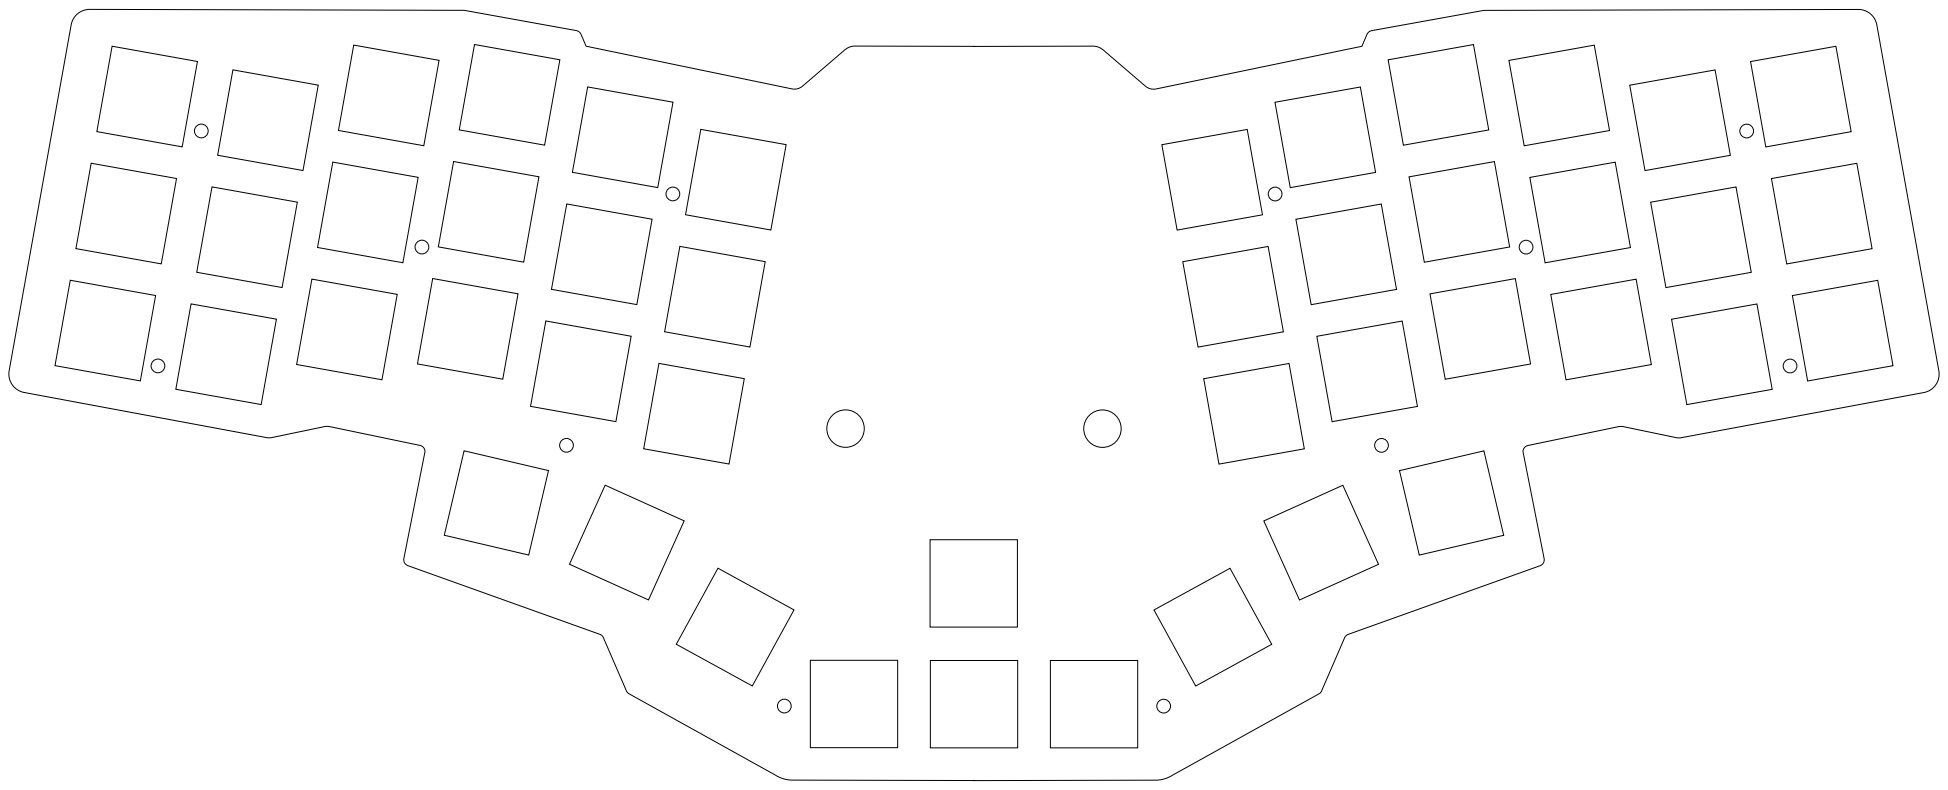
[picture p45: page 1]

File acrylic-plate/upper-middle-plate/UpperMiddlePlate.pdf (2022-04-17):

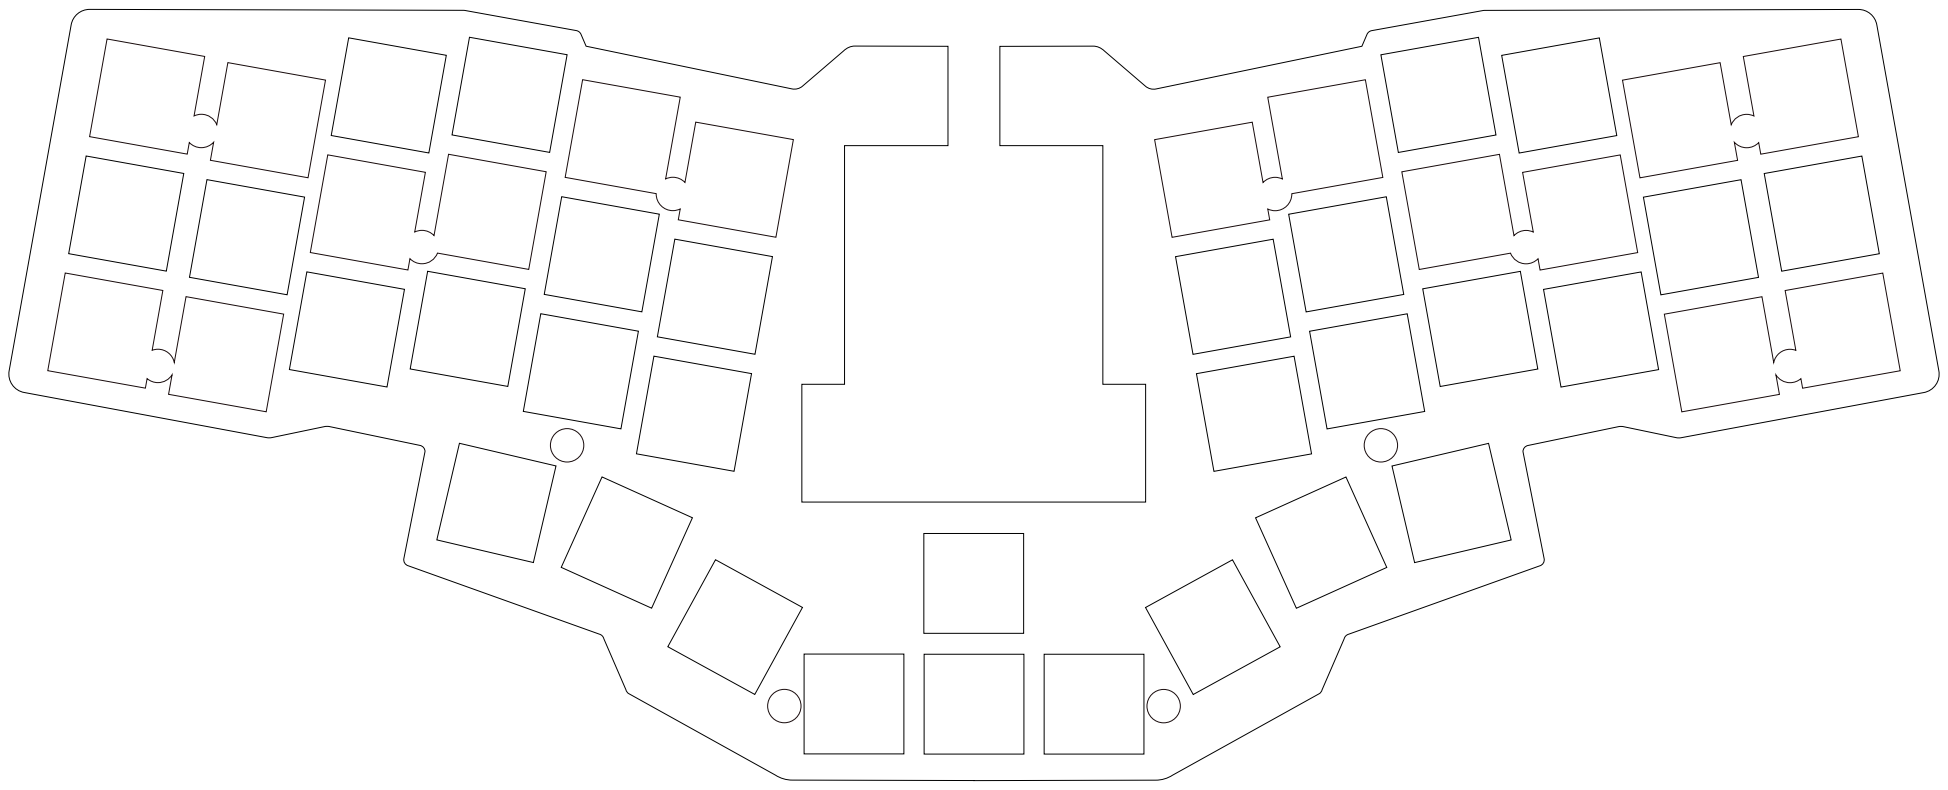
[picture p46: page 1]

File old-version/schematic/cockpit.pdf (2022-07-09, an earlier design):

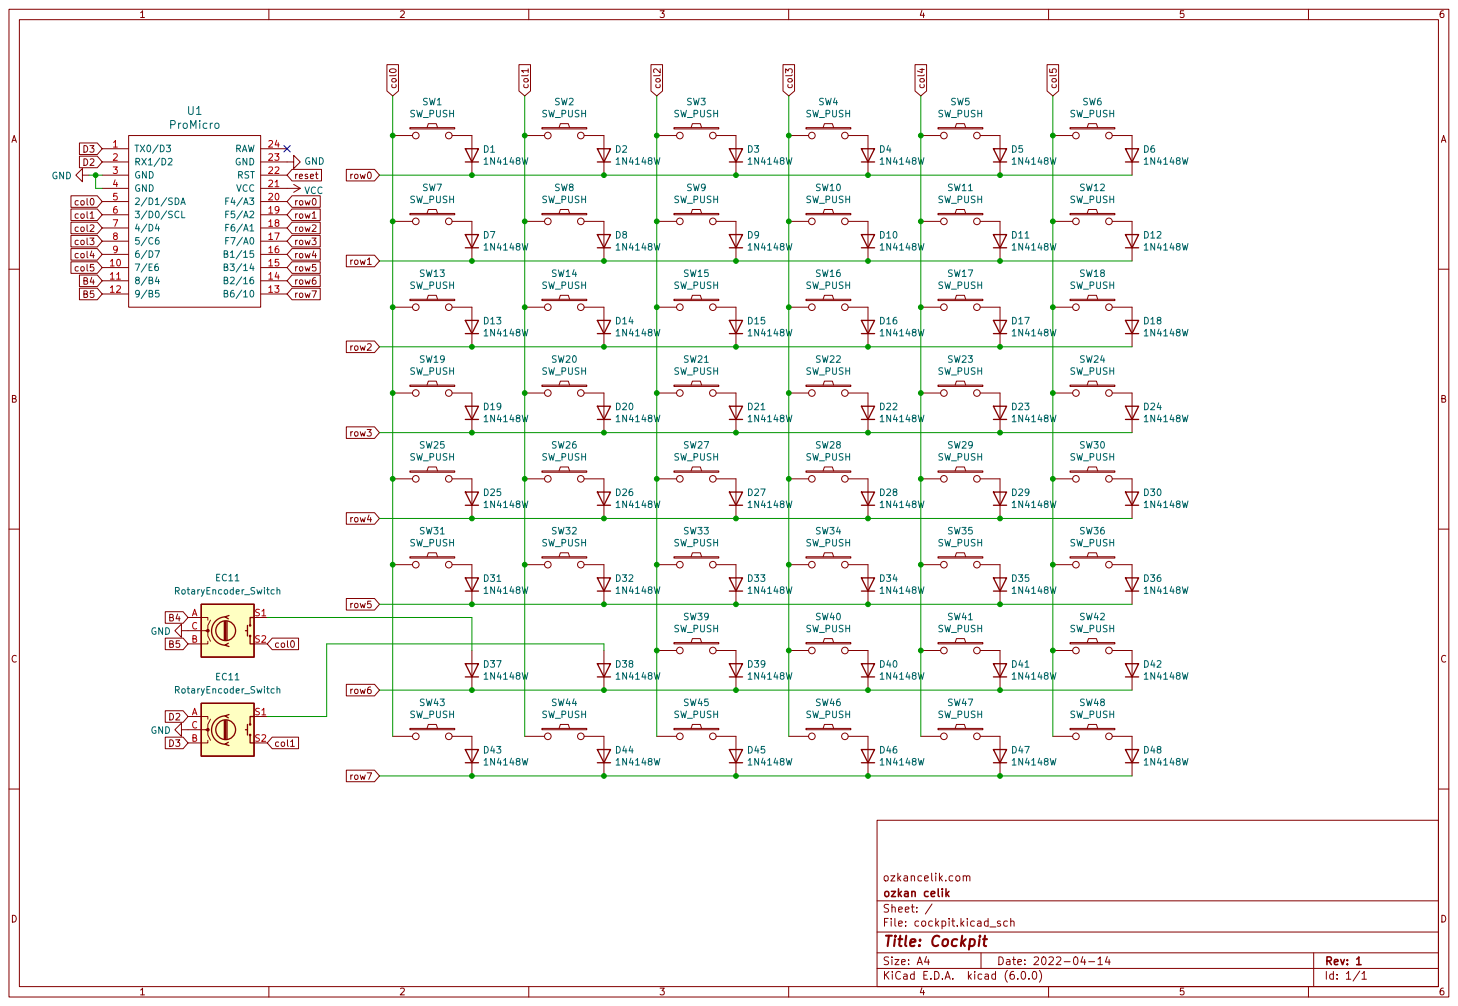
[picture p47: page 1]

ozkancelik.com
File: cockpit.kicad_sch Sheet: / ozkan celik

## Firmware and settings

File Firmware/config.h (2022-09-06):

#pragma once
#include "config_common.h"

/* USB Device descriptor parameter */
#define VENDOR_ID 0x4648
#define PRODUCT_ID 0x0001
#define DEVICE_VER 0x0001
#define MANUFACTURER ozkancelik
#define PRODUCT cockpit

/* key matrix size */
#define MATRIX_ROWS 8
#define MATRIX_COLS 6

/*
 * Keyboard Matrix Assignments
 *
 * Change this to how you wired your keyboard
 * COLS: AVR pins used for columns, left to right
 * ROWS: AVR pins used for rows, top to bottom
 * DIODE_DIRECTION: COL2ROW = COL = Anode (+), ROW = Cathode (-, marked on diode)
 *                  ROW2COL = ROW = Anode (+), COL = Cathode (-, marked on diode)
 *
 */
#define MATRIX_ROW_PINS \
    { F4, F5, F6, F7, B1, B3, B2, B6 }
#define MATRIX_COL_PINS \
    { D1, D0, D4, C6, D7, E6 }
#define UNUSED_PINS

/* COL2ROW, ROW2COL*/
#define DIODE_DIRECTION COL2ROW

#define ENCODERS_PAD_A { B4, B4 }
#define ENCODERS_PAD_B { B5, D3 }

//  #define ENCODER_RESOLUTION 4 
// #define ENCODER_RESOLUTIONS { 4, 2 }




#define SOFT_SERIAL_PIN D0  // or D1, D2, D3, E6



#define RGB_DI_PIN D2
#ifdef RGB_DI_PIN
  #define RGBLED_NUM 11
  #define RGBLIGHT_HUE_STEP 16
  #define RGBLIGHT_SAT_STEP 16
  #define RGBLIGHT_VAL_STEP 16
  #define RGBLIGHT_LIMIT_VAL 255 /* The maximum brightness level */
  #define RGBLIGHT_SLEEP  /* If defined, the RGB lighting will be switched off when the host goes to sleep */
// /*== all animations enable ==*/
  #define RGBLIGHT_ANIMATIONS
// /*== or choose animations ==*/
//   #define RGBLIGHT_EFFECT_BREATHING
//   #define RGBLIGHT_EFFECT_RAINBOW_MOOD
//   #define RGBLIGHT_EFFECT_RAINBOW_SWIRL
//   #define RGBLIGHT_EFFECT_SNAKE
//   #define RGBLIGHT_EFFECT_KNIGHT
//   #define RGBLIGHT_EFFECT_CHRISTMAS
//   #define RGBLIGHT_EFFECT_STATIC_GRADIENT
//   #define RGBLIGHT_EFFECT_RGB_TEST
//   #define RGBLIGHT_EFFECT_ALTERNATING
// /*== customize breathing effect ==*/
//   /*==== (DEFAULT) use fixed table instead of exp() and sin() ====*/
//   #define RGBLIGHT_BREATHE_TABLE_SIZE 256      // 256(default) or 128 or 64
//   /*==== use exp() and sin() ====*/
//   #define RGBLIGHT_EFFECT_BREATHE_CENTER 1.85  // 1 to 2.7
//   #define RGBLIGHT_EFFECT_BREATHE_MAX    255   // 0 to 255
#endif




/* Debounce reduces chatter (unintended double-presses) - set 0 if debouncing is not needed */
#define DEBOUNCE 5

/* define if matrix has ghost (lacks anti-ghosting diodes) */
//#define MATRIX_HAS_GHOST

/* Mechanical locking support. Use KC_LCAP, KC_LNUM or KC_LSCR instead in keymap */
#define LOCKING_SUPPORT_ENABLE
/* Locking resynchronize hack */
#define LOCKING_RESYNC_ENABLE

/* If defined, GRAVE_ESC will always act as ESC when CTRL is held.
 * This is userful for the Windows task manager shortcut (ctrl+shift+esc).
 */
// #define GRAVE_ESC_CTRL_OVERRIDE

/*
 * Force NKRO
 *
 * Force NKRO (nKey Rollover) to be enabled by default, regardless of the saved
 * state in the bootmagic EEPROM settings. (Note that NKRO must be enabled in the
 * makefile for this to work.)
 *
 * If forced on, NKRO can be disabled via magic key (default = LShift+RShift+N)
 * until the next keyboard reset.
 *
 * NKRO may prevent your keystrokes from being detected in the BIOS, but it is
 * fully operational during normal computer usage.
 *
 * For a less heavy-handed approach, enable NKRO via magic key (LShift+RShift+N)
 * or via bootmagic (hold SPACE+N while plugging in the keyboard). Once set by
 * bootmagic, NKRO mode will always be enabled until it is toggled again during a
 * power-up.
 *
 */
//#define FORCE_NKRO

/*
 * Feature disable options
 *  These options are also useful to firmware size reduction.
 */

/* disable debug print */
//#define NO_DEBUG

/* disable print */
//#define NO_PRINT

/* disable action features */
//#define NO_ACTION_LAYER
//#define NO_ACTION_TAPPING
//#define NO_ACTION_ONESHOT

/* Bootmagic Lite key configuration */
// #define BOOTMAGIC_LITE_ROW 0
// #define BOOTMAGIC_LITE_COLUMN 0

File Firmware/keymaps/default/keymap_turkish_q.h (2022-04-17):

#pragma once

#include "keymap.h"

// clang-format off

/*
 * ┌───┬───┬───┬───┬───┬───┬───┬───┬───┬───┬───┬───┬───┬───────┐
 * │ " │ 1 │ 2 │ 3 │ 4 │ 5 │ 6 │ 7 │ 8 │ 9 │ 0 │ * │ - │       │
 * ├───┴─┬─┴─┬─┴─┬─┴─┬─┴─┬─┴─┬─┴─┬─┴─┬─┴─┬─┴─┬─┴─┬─┴─┬─┴─┬─────┤
 * │     │ Q │ W │ E │ R │ T │ Y │ U │ I │ O │ P │ Ğ │ Ü │     │
 * ├─────┴┬──┴┬──┴┬──┴┬──┴┬──┴┬──┴┬──┴┬──┴┬──┴┬──┴┬──┴┬──┴┐    │
 * │      │ A │ S │ D │ F │ G │ H │ J │ K │ L │ Ş │ İ │ , │    │
 * ├────┬─┴─┬─┴─┬─┴─┬─┴─┬─┴─┬─┴─┬─┴─┬─┴─┬─┴─┬─┴─┬─┴─┬─┴───┴────┤
 * │    │ < │ Z │ X │ C │ V │ B │ N │ M │ Ö │ Ç │ . │          │
 * ├────┼───┴┬──┴─┬─┴───┴───┴───┴───┴───┴──┬┴───┼───┴┬────┬────┤
 * │    │    │    │                        │    │    │    │    │
 * └────┴────┴────┴────────────────────────┴────┴────┴────┴────┘
 */
// Row 1
#define TR_DQUO KC_GRV  // "
#define TR_1    KC_1    // 1
#define TR_2    KC_2    // 2
#define TR_3    KC_3    // 3
#define TR_4    KC_4    // 4
#define TR_5    KC_5    // 5
#define TR_6    KC_6    // 6
#define TR_7    KC_7    // 7
#define TR_8    KC_8    // 8
#define TR_9    KC_9    // 9
#define TR_0    KC_0    // 0
#define TR_ASTR KC_MINS // *
#define TR_MINS KC_EQL  // -
// Row 2
#define TR_Q    KC_Q    // Q
#define TR_W    KC_W    // W
#define TR_E    KC_E    // E
#define TR_R    KC_R    // R
#define TR_T    KC_T    // T
#define TR_Y    KC_Y    // Y
#define TR_U    KC_U    // U
#define TR_I    KC_I    // I
#define TR_O    KC_O    // O
#define TR_P    KC_P    // P
#define TR_GBRV KC_LBRC // Ğ
#define TR_UDIA KC_RBRC // Ü
// Row 3
#define TR_A    KC_A    // A
#define TR_S    KC_S    // S
#define TR_D    KC_D    // D
#define TR_F    KC_F    // F
#define TR_G    KC_G    // G
#define TR_H    KC_H    // H
#define TR_J    KC_J    // J
#define TR_K    KC_K    // K
#define TR_L    KC_L    // L
#define TR_SCED KC_SCLN // Ş
#define TR_IDOT KC_QUOT // İ
#define TR_COMM KC_NUHS // ,
// Row 4
#define TR_LABK KC_NUBS // <
#define TR_Z    KC_Z    // Z
#define TR_X    KC_X    // X
#define TR_C    KC_C    // C
#define TR_V    KC_V    // V
#define TR_B    KC_B    // B
#define TR_N    KC_N    // N
#define TR_M    KC_M    // M
#define TR_ODIA KC_COMM // Ö
#define TR_CCED KC_DOT  // Ç
#define TR_DOT  KC_SLSH // .

/* Shifted symbols
 * ┌───┬───┬───┬───┬───┬───┬───┬───┬───┬───┬───┬───┬───┬───────┐
 * │ é │ ! │ ' │ ^ │ + │ % │ & │ / │ ( │ ) │ = │ ? │ _ │       │
 * ├───┴─┬─┴─┬─┴─┬─┴─┬─┴─┬─┴─┬─┴─┬─┴─┬─┴─┬─┴─┬─┴─┬─┴─┬─┴─┬─────┤
 * │     │   │   │   │   │   │   │   │   │   │   │   │   │     │
 * ├─────┴┬──┴┬──┴┬──┴┬──┴┬──┴┬──┴┬──┴┬──┴┬──┴┬──┴┬──┴┬──┴┐    │
 * │      │   │   │   │   │   │   │   │   │   │   │   │ ; │    │
 * ├────┬─┴─┬─┴─┬─┴─┬─┴─┬─┴─┬─┴─┬─┴─┬─┴─┬─┴─┬─┴─┬─┴─┬─┴───┴────┤
 * │    │ > │   │   │   │   │   │   │   │   │   │ : │          │
 * ├────┼───┴┬──┴─┬─┴───┴───┴───┴───┴───┴──┬┴───┼───┴┬────┬────┤
 * │    │    │    │                        │    │    │    │    │
 * └────┴────┴────┴────────────────────────┴────┴────┴────┴────┘
 */
// Row 1
#define TR_EACU S(TR_DQUO) // é
#define TR_EXLM S(TR_1)    // !
#define TR_QUOT S(TR_2)    // '
#define TR_CIRC S(TR_3)    // ^ (dead)
#define TR_PLUS S(TR_4)    // +
#define TR_PERC S(TR_5)    // %
#define TR_AMPR S(TR_6)    // &
#define TR_SLSH S(TR_7)    // /
#define TR_LPRN S(TR_8)    // (
#define TR_RPRN S(TR_9)    // )
#define TR_EQL  S(TR_0)    // =
#define TR_QUES S(TR_ASTR) // ?
#define TR_UNDS S(TR_MINS) // _
// Row 3
#define TR_SCLN S(TR_COMM) // ;
// Row 4
#define TR_RABK S(TR_LABK) // >
#define TR_COLN S(TR_DOT)  // :

/* AltGr symbols
 * ┌───┬───┬───┬───┬───┬───┬───┬───┬───┬───┬───┬───┬───┬───────┐
 * │   │   │ £ │ # │ $ │ ½ │   │ { │ [ │ ] │ } │ \ │ | │       │
 * ├───┴─┬─┴─┬─┴─┬─┴─┬─┴─┬─┴─┬─┴─┬─┴─┬─┴─┬─┴─┬─┴─┬─┴─┬─┴─┬─────┤
 * │     │ @ │   │ € │   │ ₺ │   │   │   │   │   │ ¨ │ ~ │     │
 * ├─────┴┬──┴┬──┴┬──┴┬──┴┬──┴┬──┴┬──┴┬──┴┬──┴┬──┴┬──┴┬──┴┐    │
 * │      │ Æ │ ß │   │   │   │   │   │   │   │ ´ │   │ ` │    │
 * ├────┬─┴─┬─┴─┬─┴─┬─┴─┬─┴─┬─┴─┬─┴─┬─┴─┬─┴─┬─┴─┬─┴─┬─┴───┴────┤
 * │    │   │   │   │   │   │   │   │   │   │   │   │          │
 * ├────┼───┴┬──┴─┬─┴───┴───┴───┴───┴───┴──┬┴───┼───┴┬────┬────┤
 * │    │    │    │                        │    │    │    │    │
 * └────┴────┴────┴────────────────────────┴────┴────┴────┴────┘
 */
// Row 1
#define TR_PND  ALGR(TR_2)    // £
#define TR_HASH ALGR(TR_3)    // #
#define TR_DLR  ALGR(TR_4)    // $
#define TR_HALF ALGR(TR_5)    // ½
#define TR_LCBR ALGR(TR_7)    // {
#define TR_LBRC ALGR(TR_8)    // [
#define TR_RBRC ALGR(TR_9)    // ]
#define TR_RCBR ALGR(TR_0)    // }
#define TR_BSLS ALGR(TR_ASTR) // (backslash)
#define TR_PIPE ALGR(TR_MINS) // |
// Row 2
#define TR_AT   ALGR(TR_Q)    // @
#define TR_EURO ALGR(TR_E)    // €
#define TR_LIRA ALGR(TR_T)    // ₺
#define TR_DIAE ALGR(TR_GBRV) // ¨ (dead)
#define TR_TILD ALGR(TR_UDIA) // ~ (dead)
// Row 3
#define TR_AE   ALGR(TR_A)    // Æ
#define TR_SS   ALGR(TR_S)    // ß
#define TR_ACUT ALGR(TR_SCED) // ´ (dead)
#define TR_GRV  ALGR(TR_COMM) // ` (dead)

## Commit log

2022-07-09 fix: schematic (ENCODERS PAD B)
    [cockpit.kicad_sch]
2022-09-06 PCB version
    [BottomPlate.dxf, LowerMiddlePlate.dxf, RivetingPlate.dxf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]
2024-03-18 Add: dxf file
    [bottom.dxf, lower-middle-plate.dxf, top.dxf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]
2024-03-18 Up: plate
    [lower-middle-plate.dxf, top.dxf, upper-middle-plate.dxf]
2024-03-19 Add: cockpit_hotswap
    [Cockpit.kicad_sch, bottom.dxf, bottom_plate.dxf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]
2024-03-20 add: pro_micro cover
    [top.dxf]
